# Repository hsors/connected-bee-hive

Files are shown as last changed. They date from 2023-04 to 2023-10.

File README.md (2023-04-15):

# ardbeescale-for-dummies


This repo includes the code of a a connected bee hive project together with a 65 pages document explaining the project in all details, including hardware and software 

My implementation is classical (Arduino/LoRaWan/NodeRED/InfluxDB/Grafana) but I also have included a Google Sheet integration retrieving the hive data in a google sheet, which is convenient for calibration purposes. The data being transmitted are weight, external temperature, humidity and pressure plus internal brood temperature. The data are transmitted every 15mn by default but this is configurable by sending an ad hoc downlink to the hive (a python script is provided to send downlinks to the hives). 

My code includes a weight temperature compensation algorithm using a nonlinear model which has proven to be effective and which is described precisely in the document. 

My connected bee hives include a small sirup pump allowing to feed the hives remotely. This is both convenient when the apiary is not close by and very effective to develop the hives in the spring or before winter (feeding with a small quantity of sugar very often seems to be more effective than a bigger quantity less often). The application includes a smartphone app from which the user can trigger the pumps (the app is communicating with a set of python scripts which send some uplink information to the app and get input from the app to send downlinks to the hives). From the same app, it’s possible to send a downlink which prevent the hive from sending data during a certain pre-determined time (when hives are open, we want to avoid to plot a wrong point on the hive weight curve). 

My apiary being too far away from the closest LoRaWAN gateway I had to add one (with the 4G option), which is powered from a 12V battery charged with PV panels. The gateway being quite power angry, it is switched on by an “energy saving device” only when uploads are transmitted by the scales. My code includes therefore a mechanism which synchronizes the time of each scale and the one of the energy saver device with TTN time. The  time synchronization logic is controlled by two python scripts which can be launched either manually or at regular time intervals such as once a week, to set the time of the nodes: the first script is listening to the next uplink sent by a node. The second one is triggered when this next uplink is received, at which time it sends a “set time” downlink to the node with the time of this last received uplink to which the duration between two measures is added.

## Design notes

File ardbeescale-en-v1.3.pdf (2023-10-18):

Henri SORS / h@sors.net / +33 672 99 31 36 / skype : hsors01 | ardbeescale.docx

# ArdBeeScale Project

CONTENT

1 | PROJECT PRESENTATION & TECHNOLOGICAL CHOICES | 3
1.1 | SYSTEM PRESENTATION | 3
1.2 | DEVELOPMENT ENVIRONMENT : PLATFORMIO | 4
1.3 | MICRO CONTROLLER CHOICE | 5
1.4 | DATA TRANSMISSION: LORA | 7
1.4.1 | USING AN EXISTING GATEWAY | 7
1.4.2 | USING A NEW GATEWAY | 8
1.4.3 | GATEWAY CONNECTION WITH A 4G KEY | 9
1.4.4 | SETTING UP A NODE ON TTN NETWORK. | 9
1.4.5 | PAYLOADS DECODING | 10
1.5 | ENERGY | 10
2 | SOFTWARE | 11
2.1 | MICRO CONTROLLER SOFTWARE | 11
2.1.1 | LORA LIBRARY CHOICE | 11
2.1.2 | LMIC-NODE INSTALLATION | 11
2.1.3 | HX711 LIBRARY | 13
2.1.4 | BME280 LIBRARY | 14
2.1.5 | LIBRARIES FOR THE DS18B20 TEMPERATURE SENSOR | 15
2.1.6 | PAYLOADS FORMATS | 16
2.1.7 | MAIN SKETCH –UPLINKS AND DOWNLINKS PROCESSING | 18
2.1.8 | MAIN SKETCH – POWER MANAGEMENT | 18
2.1.9 | MAIN SKETCH; TIME MANAGEMENT | 19
2.1.10 | DEALING WITH UNEXPECTED HANGS THANKS TO THE INTEGRATED WATCH DOG | 20
2.2 | JS CODE FOR PAYLOAD DECODING (TO BE LOADED ON TTN CONSOLE) | 20
3 | INTEGRATION WITH GOOGLE SHEET | 21
3.1 | MQTT | 21
3.1.1 | PROTOCOL | 21
3.1.2 | MOSQUITTO | 21
3.1.3 | MQTT & PYTHON | 23
3.2 | PYTHON CODE RUNNING ON RASPI SERVEUR | 24
3.2.1 | PROGRAMS & DATA ORGANIZATION | 24
3.2.2 | PYTHON CONFIGURATION FILE | 25
3.2.3 | RETRIEVING DATA FROM MQTT AND TEMPORARY STORAGE | 25
3.2.4 | DATA STORAGE IN A GOOGLE SHEET FILE | 26
3.2.5 | INSTALLATION | 28
4 | BLYNK | 29
4.1 | GENERAL PRINCIPLE | 29

Ardbeescale | Page 2 | Novembre 2021
4.2 | BLYNK SET-UP | 29
4.3 | PROGRAMMING | 30
4.4 | BLYNK INSTALL ON RASPBERRY | 32
4.5 | CONFIGURATION OF BLYNK APP | 32
4.6 | UPDATE AS OF FEBRUARY 2023 | 33
5 | NODE-RED – INFLUXDB – GRAFANA INTEGRATION | 33
5.1 | PRINCIPLE | 33
5.2 | NODE-RED | 35
5.2.1 | FETCHING UPLINKS IN NODE-RED | 36
5.2.2 | DATA STORAGE IN INFLUXDB | 37
5.2.3 | SENDING DOWNLINKS | 38
5.2.4 | NODE-RED DASHBOARD ON A SMARTPHONE | 39
5.3 | VISUALIZATION WITH GRAFANA | 39
6 | HARDWARE & WIRING | 40
6.1 | LOAD CELL & SUPPORT FRAME | 40
6.2 | WIRING OF THE MICRO CONTROLLERS AND ASSOCIATED CONNECTORS | 41
6.2.1 | WIRING OF BME280 SENSOR | 41
6.2.2 | WIRING OF THE HX711 BOARD | 42
6.2.3 | WIRING OF THE RELAY BOARD | 42
6.2.4 | MICROCONTROLLER WIRING | 42
6.2.5 | MODIFICATION OF THE BATTERIE ENCLOSURE | 48
6.2.6 | CHARGING THE BATTERY | 48
6.2.7 | CONTENT AND CHOICE OF THE ENCLOSURE | 48
6.2.8 | MOUNTING THE ENCLOSURE ON THE SCALE | 50
7 | WEIGHT MEASURE ACCURACY | 50
8 | HOW TO ACCESS A GOOGLE SHEET FILE FROM PYTHON SCRIPT | 51
9 | WEIGHT TEMPERATURE COMPENSATION | 51
9.1 | PROBLEM STATEMENT | 51
9.2 | PROPOSED NONLINEAR MODEL | 53
9.3 | IMPLEMENTATION | 57
10 | POWER SAVING UNIT | 58
10.1 | INTRODUCTION | 58
10.2 | ABOUT THE HARDWARE | 59
10.3 | SOFTWARE | 60
10.4 | UPLINKS SENT BY THIS ENERGY SAVING DEVICE: | 62
10.5 | SETTING UP THE TIME OF THE ENERGY SAVER UNIT. | 62
10.6 | MAKING SURE EVERYTHING IS IN SYNCH… | 63
11 | - LIST OF FILES | 64
12 | - SETTING-UP THE SYSTEM… | 65

Ardbeescale | Page 3 | Novembre 2021

### 1 PROJECT PRESENTATION & TECHNOLOGICAL CHOICES

### 1.1 System presentation

Main features of « ardbeescale » :

- Hive weight measurement with a Bosche H40 load cell
- Temperature, pressure and humidity measurement with a BME280 sensor
- Internal hive temperature measurement with a DS18B20 one wire sensor
- Data transmission on the LoRaWAN TTN network at a configurable frequency from once per minute to once per 24H
- Use of an Arduino low consumption microcontroller (Adafruit LoRa Feather M0, based on SAMD21 processor), powered by two 18650 batteries (3.7V) rechargeable on an external USB plug.
- The device includes a relay and the ad hoc hardware & software needed to remotely trigger a syrup pump from a smartphone

TTN's LoRaWAN network is widely present in my region (Grenoble/France, the home of Cycleo, the company that invented LoRa technology, which Semtech, a US company bought in 2012) and therefore in many places in this region it is possible to install a LoRa based hives using existing gateways. However my apiary happens to be a bit too far away from the closest gateway and I have therefore chosen to add one, which is connected to the Internet through a 4G key and powered by a 12V battery connected to two PV panels.

To retrieve the data emitted with LoRa protocol by the hives, I use a raspberry pi that communicates via the internet with the TTN network. Two types of integration have been developed:

- Through two python programs that run on the raspberry pi
- getdataFromUplink.py which retrieves (thanks to the MQTT protocol) the data sent by the hives to the TTN server and places them in a directory of the raspberry server
- storedata.py which permanently checks this directory and stores the data that have been placed in it (by getdataFromUplink.py) in a google sheet file in which they are visualized on charts. These programs are designed to manage a maximum of 6 connected hives per apiary on a Google sheet file.

This integration had some reliability problems that seem to be related to the availability of the google sheets files (I didn't manage to implement the error checks that could allow to totally get rid of these problems and it turns out that the storedata.py program crashes from time to time, about once a month for a reason that I failed to identify)

- Based on the limitation of the google sheet integration, another one has been developed using a standard IOT stack: the data are retrieved using the MQTT protocol, using an MQTT node on nodeRed that listens to the TTN brocker. Another node of nodeRed stores the data in an influxDB "time series" database and the data are visualized using Grafana.

The data transmitted from the hive to the server (uplinks) are weight, external temperature, internal temperature, humidity, pressure and battery voltage, all on 8 bytes. A last byte is added to secure the transmission of downlinks: it contains the value of the last downlink received allowing to check that this downlink has been received and processed.

The data transmitted by the server to the hive as downlinks allows :

- To change the frequency of measurements
- To trigger the pump feeding the hive with sirup
- To hold measurements for a certain time in order to avoid false measurements during hive manipulation which otherwise would pollute the weight curve of the corresponding hive.
- To reset the value of the last downlink received by the server
- To set the time of the micro controller in order to be able to take measurement at precise moments. This is needed because in winter there is not enough energy to power the gateway permanently; a special device (hso-energysaver) has been developed to switch it ON at

Ardbeescale | Page 4 | Novembre 2021

precise moments and the hives should transmit data at the same time; hence the need to set the same time on all devices). Details in 2.1.9

The enclosure includes following inputs / outputs:

- Three female Jack connectors :
- Two that are very close to each other (mounted in parallel) allow to bring in and out (to the next hive) the 12V necessary for powering the pump
- One is apart and brings 12V to the pump
- A micro USB connector (connected to the one of the Adafruit board itself) is available on the enclosure. It allows to recharge the batteries (because the board includes a charger) and to reprogram the processor without having to open the case.
- A push button triggering the pump in order to easily calibrate it.
- There is no connector for either the BME280 sensor or for the load cell: corresponding cables pass through the housing.

The enclosure also includes an on/off button which is needed to easily reprogram the device without opening it (reprogramming the device is possible only during program start-up; later on the device is almost all the time in sleep mode and would not respond to the serial port)

The firmware also includes a temperature compensation model that reduces fluctuations in weight measurements when temperature changes. See chapter Error! Reference source not found.

### 1.2 Development environment : platformIO

platformIO seems to be a quite powerful and widely used development tool, the most common alternative being Arduino IDE which is deemed to be less feature full and does not have a debugger. The installation procedure of platformIO can be found here. (https://circuitdigest.com/microcontroller-projects/programming-arduino-using-platform-io-to-blink-an-led) There is also a good and clear explanation video here (https://dronebotworkshop.com/platformio/) including explanations in text form.

When programs developed with Arduino IDE are used (.ino extension), it’s needed to convert them into platformIO file (.cpp extension). See explanations in the platformIO doc here. (https://docs.platformio.org/en/latest/faq.html#convert-arduino-file-to-c-manually) It is the same code, the main difference being the order in which functions are declared.

It seems to be possible to use Python on platformIO with Arduino (by charging the ad hoc extension) but I haven’t tried. Documentation is here. (https://code.visualstudio.com/docs/python/python-tutorial)

To use platformIO, Visual Studio Code has to be loaded first and then the PlatformIO plug-in (by clicking on the "extension" icon, type platformIO and it will load automatically).

A good video tutorial from a Canadian guy is available here. (https://www.youtube.com/watch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)

In platformIO, different projects are stored in different sub directories of /platformIO/Projects on the Mac. You can open several projects at the same time in the same workspace. To add a project in a workspace select " add folder to workspace " (if you just do " open folder " it opens the project but it closes everything else, including the current workspace). To remove a project from the open workspace select "remove folder from workspace".

You can save a workspace containing several projects. Re opening it opens all the projects.

Sometimes and for some reasons, I met difficulties in loading my projects in PlatformIO (impossible a add a folder). I resolved this by clicking on the small “home” icon and then could choose the project to be loaded… I need to dig more in PlatformIO to fully understand how it works…

Libraries installation :
Click on the home icon, then choose "library". The library is installed only for the project that needs it. The library is added in the .pio directory (therefore not visible in the finder).

Ardbeescale | Page 5 | Novembre 2021

Alternatively, it’s possible to add a library by adding the name of its libdeps (library dependency) in platform.ini which is project specific:

lib_deps =
fabyte/Tiny BME280 @ ^1.0.2
In fact it seems that adding some libraries will automatically add this line to platformio.ini but is other instances, one need to load the library as described above and also add the reference to it in the file platformio.ini (as explained in the “installation” tab available once you have added the library using the “home” icon of PlatformIO. Need to double check as I am not fully sure…

At compilation time, the library will be loaded and it will show up in folder .pio/libdeps. In order to remove it, simply remove its reference in the libdeps and remove the directory of this library which resides in .pio/libdeps
Official documentation of platformio.org is here. (https://docs.platformio.org/en/latest/librarymanager/quickstart.html)

For information I have met an issue with PlatformIO which I was unable to resolve by myself. For some reasons, all of a sudden it became impossible to list the installed libraries. Clicking on the home icon and then on Libraries et selecting “installed libraries” triggered a pop up error message saying:

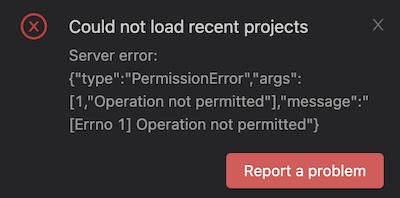
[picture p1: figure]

I posted a question about this issue on PlatformIO community forum and a PlatformIO support guy instructed me to type the following command in the system terminal:
rm ~/.platformio/homestate.json
It resolved the problem but I completely fail to understand why and what happened.

### 1.3 Micro controller choice

Initially I started with a Moteino (https://lowpowerlab.com/shop/product/99) which is a very small size Arduino compatible board (ATmega328p processor), proposed par lowpowerlab. (http://www.lowpowerlab.com/) This Moteino board has a piggy back LoRa option, connected to the SPI bus. The supplier is in the US (knowing the radio module comes from China) but there is now a distributor in Germany (Welectron) which is selling Moteino in Europe with the a European frequency option (RF95).

But in the end, because Moteino turns out to be a 8bits processor with not enough memory for the "standard" LoRaWan library (only the old version of the library which is not supported anymore would work) I had to drop this board and I finally selected Adafruit Feather M0 with RFM95 Lora Radio -900MHz (https://www.adafruit.com/product/3178) (which can work at 868MHz, the authorized frequency in Europe). I paid 51€ttc on Amazon. Documentation is here. (https://cdn-learn.adafruit.com/downloads/pdf/adafruit-feather-m0-radio-with-lora-radio-module.pdf) This board, which is Arduino zero compatible, is powered with 3.3V and is based on an Atmel 32 bits ARM ATSAMD21G1processor. It carries much more memory than Moteino and includes a micro USB interface with the ad hoc charger circuitry allowing to recharge the battery by plugging a micro USB cable connected to a power source. It also includes a battery connector.

Ardbeescale | Page 6 | Novembre 2021

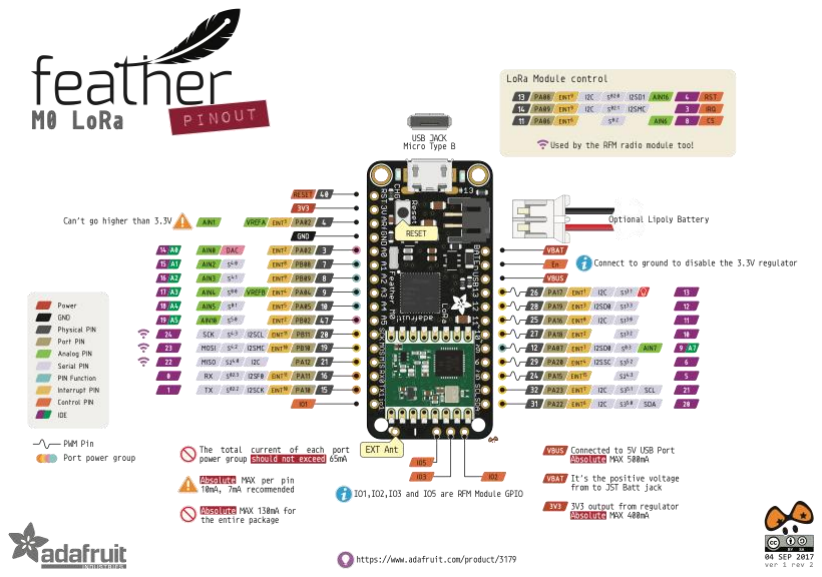
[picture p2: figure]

This board can be powered with a 5V power supply connected to micro USB plug; the internal circuitry will convert the voltage to 3.3V.

There | is | an | HX711 | (A/D | converter | for | the load | cell) driver | available | for | this | board
(https://github.com/bogde/HX711) which is the one used by hiveeyes.

Adafruit busIO driver must also be loaded in order to be able to use the I2C bus, which needed for the BME280 device (temperature, humidity and pressure sensor).

For the antenna, I initially bought one on Amazon for 11€ but when testing this antenna I found that I lost 10 to 20db on the RSSI of the received signal compared to an antenna made of a simple wire of ¼ of the wavelength. So I abandoned the idea of an SMA antenna and just used a simple wire that I tilted a bit to fit into the box. To make something more sophisticated, the best thing to do is to refer to this forum (https://lowpowerlab.com/forum/rf-range-antennas-rfm69-library/alternative-pcb-dipole-designs-(433-868-and-915mhz)/) which explains how to make a half wavelength dipole antenna using the right (https://www.amazon.com/RP-SMA-Female-Pigtail-Antenna-Coaxial/dp/B072VWKXCR/?th=1) cable of the right length to connect it to the board.

Ardbeescale | Page 7 | Novembre 2021

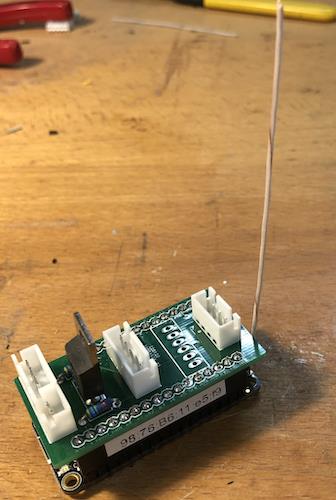
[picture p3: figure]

This is a picture of the module (with add-on board plugged in, as explained later in this document) equipped with a ¼ wavelength antenna (8.62cm):

### 1.4 Data transmission: LoRa

It was a Grenoble-based company that developed LoRa (Cycleo, created in 2010), bought by Semtech two years later for $5M... The LoRa alliance was created in 2012.

One way to become familiar with the technology is to read the this page (https://www.thethingsnetwork.org/docs/devices/node/) presenting what they call "the things node" which is a simple device allowing to make tests. This same page has a menu that presents other devices.

LoRa protocol is close to the hardware but there is an associated network protocol, called LoRaWan.

The web site www.thethingsnetwork.org manages a free LoRaWan network. There is a « quick start (https://www.thethingsnetwork.org/docs/quick-start/) » page containing multiple explanation videos and listing several popular development boards. In particular, there is a link on some videos from TTN explaining how to do the set-up of a LoRa device or a LoRa gateway and which speaks about payload formaters (for getting the data correctly formatted).

The TTN community offers a tool called "the things stack" which allows to connect to a LoRaWan network and to manage all LoRa devices, including end nodes and gateways. The same tool allows to format the received data so that it is readable (payload formater). On TTN's LoRaWAN network, you can connect to the network even if you don't have a gateway, any gateway on the network being usable, as long as it is accessible (=near enough).

There is very wide variety of LoRa compatible sensors of all kinds: see a list on the TTN site here. (https://www.thethingsnetwork.org/device-repository/)

With TTN, there are limitations in the number of messages transmitted and their length (max: 30s air time/day. See TTN « fair policy (https://www.thethingsnetwork.org/forum/t/fair-use-policy-explained/1300) ».

TTN web site has a documentation page (https://www.thethingsnetwork.org/docs/lorawan/) on LoRa and LoRaWAN.

### 1.4.1 Using an existing gateway

TTN publishes a web page with the latest network coverage indications: https://ttnmapper.org

Ardbeescale | Page 8 | Novembre 2021

This mapping can be updated by users using a TTN tool. There is a page on the TTN site that gives all the explanations

Most cities and their suburbs are covered by the TTN network.

### 1.4.2 Using a new gateway

To use the hives in a somewhat deserted place (= not covered by a LoRa gateway of the TTN network), it is necessary to set up a new LoRaWan gateway and hook it up to the TTN network. See possible solutions on this page. (https://www.thethingsnetwork.org/docs/gateways/) The best is probably to buy the gateway offered by thethingsindustries here. (https://fr.rs-online.com/web/p/modules-de-developpement-de-communication-et-sans-fil/2018876) There is a (https://www.thethingsnetwork.org/forum/t/ttig-outdoor-housing-with-omni-antenna-in-1-hour/29523) thread on the forum that explains how to transform the indoor gateway into an outdoor gateway. I also asked the question of choice of gateway on the TTN forum and I received an (https://www.thethingsnetwork.org/forum/t/choosing-a-gateway/53040/18) answer that seems interesting if you want an outdoor gateway.

There is also a Raspi HAT which looks interesting and is unexpensive here (https://www.robotshop.com/eu/fr/hat-raspberry-pi-lora-gps.html) but I was told on the forum that it doesn’t do the job correctly.

There is a page (https://www.thethingsnetwork.org/docs/gateways/start/build/) on TTN explaining how to make its own gateway and which lists all existing LoRaWan gateways.

### 1.4.2.1 Installing the TTIG gateway

I started by using an indoor gateway (the things indoor gateway also called TTIG). For memory, on this gateway, EUI is 58A0CBFFFE802B8B, WIFI code is wJdMxcHv and in the console I have chosen the id ttig-hso1. Installation instructions are here. (https://www.thethingsindustries.com/docs/gateways/thethingsindoorgateway/)

Note: once the gateway has been connected to the TTN network, it is easy to change the WIFI network to which it is connected: press the set-up button for 10s (until the LED flashes orange), this will turn the gateway into a WIFI access point which SSID is MINIHUB-XXXXXX. We then need to connect to this
access point (WIFI password is wJdMxcHv in my case), and go to the page | 192.168.4.1 | and click
"save & reboot" after selecting the network on which we want the gateway to connect.

Attention : there is a known bug in the TTIG indoor gateway: if the gateway is requested less than 1 time every X minutes (I think X is around 15), the gateway disconnects the LoRa nodes and then refuses all the downlinks coming from them.

### 1.4.2.2 Installation of the Dragino gateway DLOS8 Outdoor

I also installed a Dragino outdoor gateway.

When powered on, it exposes a WIFI network called dragino-xxxxxx which password is dragino+dragino. Once connected, the gateway can be accessed at address 10.130.1.1

## User Name: root Password: dragino

We can then configure the WIFI access (need to check the box "Enable WIFI WAN client" which by default is not)

Ardbeescale | Page 9 | Novembre 2021

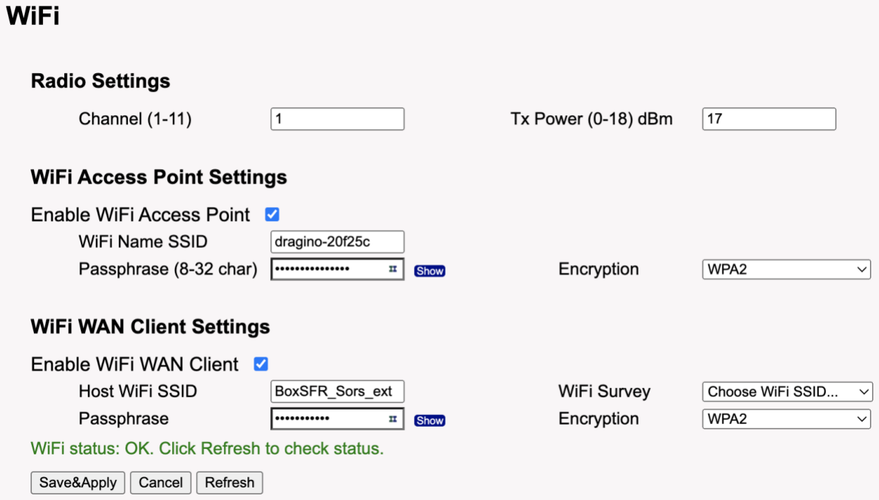
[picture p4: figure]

Meaning of the gateway LEDs :

✓ SOLID GREEN: DLOS8 is alive with LoRaWAN server connection.

## ✓ BLINKING GREEN:

a) Device has internet connection but no LoRaWAN Connection.
or
b) Device is in booting stage, in this stage, it will stay BLINKING GREEN for several seconds and then RED and YELLOW will blink together.

✓ SOLID RED: Device doesn’t have Internet connection.

Then we need to create the gateway on TTN network, using the following link : https://eu1.cloud.thethings.network/console/gateways

The "gateway Id" can be found in the LoRaWAN menu of the Dragino gateway configuration page. This is also where you choose the "server address" (eu.cloud.thethings.network) and the service provider (The Things Network v3).

### 1.4.3 Gateway connection with a 4G key

Initially I tried to use a 4G key as a WIFI "access point", the dragino being supposed to connect to Internet through this access point. For some reason (which I fail to understand), the dragino refuses to connect to this access point even though it connects without any problem my home WIFI access point.

Even if I bought the Dragino DLOS8 gateway without the 4G option (the “WIFI only” version was less expensive), I realized that the product was actually including a slot for a SIM card and when I tried to plug a SIM card in it, the device quickly connected to the Internet after I correctly configured it. What a piece of luck !

1.4.4 Setting up a node on TTN network.

There are two ways to activate a node on TTN: OTAA (Over the Air Activation) and ABP (Activation By Personalization). I understand that OTAA is preferable because the corresponding protocol

Ardbeescale | Page 10 | Novembre 2021

includes a handshake that seems to guarantee better security. Each type of activation involves a different code on the micro controller; I have used the OTAA code.

Procedure :

1. Go to the TTN console in the "Applications" section
2. Create a new application and give it a "unique application ID".
3. Then create the new device (node). There are two options to create a new device; choose "Manually" and "Node".
4. Specify which version of TTN is supported by the library. You have to search in the library files to find this information which is in the library.properties file (1.0.3 in my case)
5. Fill frequency plan (Europe)
6. Click on "generate"; the system creates a unique deviceEUI. (EUI means "Extended Unique Identifier").
7. The appEUI (or joinEUI) is to be filled with 0's if the device you want to register does not have a specified devEUI (which is the case for DIY devices).
8. The appkey is generated by the system when you press the "generate" logo.)
9. The "end Device Id" has to be filled in with a string of your choice. Be careful when you create a device Id, deleting it does not really remove it from the TTN database and it is impossible to create a new device Id that is the same as the one you have deleted.
10. Click on « generate » so that the system creates the device on TTN

See section 2.1.2 LMIC-node (text in blue) for explanation on how to update the library parameters for the newly created node.

### 1.4.5 Payloads decoding

The TTN console allows you to load a small javascript program that will retrieve the data received by the node and decode them by loading them into different variables that can be transmitted and retrieved by a python program running the paho library. See details in section 2.2

### 1.5 Energy

The power of LoRa emission is apparently adjustable by software (I do not know how...)

It is indicated in the manual of the Feather M0 LoRa board that with a transmission power of 20dBm, a current of 130mA is needed during 70ms in order to transmit a payload of 20 bytes. Therefore sending such a payload requires an energy amount equal to :

### E = 0.13 × 7 × 10⁻²A. s = 0.13 × 7 ×

10⁻²

### 3600 = 2.5μA. ℎ

It is therefore not the sending of payloads that consumes a lot of energy even if we send them regularly. If we send 6 payloads per hour, each with 20 bytes, the energy consumed each day is 360 μA.h, meaning that a single battery could last several years.

However, the quiescent current of the micro-controller together with its radio is much higher: 13mA total, including ~2mA is for the radio itself. This is about 300mAh, meaning that a 3000mAh battery would last 10 days... It is therefore essential to put the controller in standby mode between measurements if we want to achieve a reasonable battery lifetime.

It seems that the power consumption is very variable depending on the software options chosen. See this blog (https://tinkerman.cat/post/low-power-weather-station-bme280-moteino/) which gives examples (weather station using a moteino). The main idea is to put the processor in sleep mode and to wake it up at regular interval using timer interruptions

Information on power consumption here. (https://www.arduino.cc/en/Tutorial/ArduinoZeroPowerConsumption)
See also a good explanatory video here (https://www.youtube.com/watch?v=wmWqkJ97Zsc) with the associated blog (with the code) here. (https://forcetronic.blogspot.com/search?q=SAMD21+sleep) The principle consists in using the library RTCzero.h which uses the real time clock in order to wake-up the chip after a predefined period of sleep.

The author explains that it’s possible to change the source of the RTC clock, which by default is the external clock (you can choose an internal clock) and that this saves 10µA at the cost of a certain

Ardbeescale | Page 11 | Novembre 2021

loss of precision (10µA is 24mA.h in 100 days, so it is not worth optimizing by losing precision). You can find the documentation of RTCZero on arduino.cc (https://www.arduino.cc/reference/en/libraries/rtczero/) web site.

The problem in our case is that we can't stop the processor anywhere without disturbing the timing of LMIC.

The only way I found to interrupt the processor without messing up the LMIC timing is to introduce the sleep at the end of the routine that handles the event « EV_TXCOMPLETE ». It’s also necessary to delete the last line of the « doWorkCallback » callback function which reschedules the callback function [os_setTimedCallback(…)] and replace it, at the end of the code treating the event EV_TXCOMPLETE with a line launching immediately the callback function [os_setCallback()] as soon as the processor wakes-up. The sleep time of the processor is equal to the interval between two consecutive measurements as specified in the constant DO_WORK_INTERVAL_SECONDS in platformIO.ini file (in reality it will be a little bit longer because you have to add to this time the execution time of the callback function and the processing of the following events (about ten seconds in total) plus the time needed to process the downlinks if there are any (this can be quite long in the case of a downlink triggering the pump because the routine processDownlink() waits until the pump turns off before returning).

Power consumption calculations: the board consumes about 13mA when it is awaken and it stays awaken for about 8 seconds to send its uplinks each time it is woken up. If we send 4 uplinks per hour, the daily consumption will be :

E =

13×10⁻³×8

3600

× 4 × 24 = 2.77mA. ℎ, which is about 1A.h per annum. In reality this is higher, which

means that the whole process can be improved.

### 2 SOFTWARE

### 2.1 Micro Controller Software

### 2.1.1 LoRa library choice

This page on TTN, (https://www.thethingsnetwork.org/forum/t/overview-of-lorawan-libraries-howto/24692/) explains that the original library from IBM has been ported and has forked. Now the last version to be used preferably is the MCCI LMIC (https://github.com/mcci-catena/arduino-lmic) version, the original version Classic LMIC (https://github.com/matthijskooijman/arduino-lmic) being a possible solution when RAM space is limited (which was the case with Moteino that I initially tested, before dropping it because the corresponding library is not supported anymore; hence the move to Adafruit board)

This library, which is to be loaded on PlatformIO or on the Arduino IDE, gives some examples of applications but it specifies that these examples are limited and suggests to use rather the work of Lopes Parente : LMIC-Node (https://github.com/lnlp/LMIC-node) available on github. This is a complete application example, sending uplinks et receiving downlinks, using PlatformIO development environment and preconfigured for a variety of different LoRa board, including the Adafruit board that I chose. It’s also a good idea to have a look at the Adafruit site which includes a section showing how to set-up their board for TTN. It’s here (https://learn.adafruit.com/the-things-network-for-feather/overview) and it includes explanation on the code and how to decode the « payloads »

Here are other possibly useful references :

1) I have found a Dutch person which has used the LMIC library with the same HF module with an Arduino. See here. (https://www.mobilefish.com/developer/lorawan/lorawan_quickguide_build_lora_node_rfm95_arduino_uno.html) But the proposed activation method is ABP and not OTAA.
2) There is also a videao from Andreas (https://www.youtube.com/watch?v=duwUwXt-hs8) Spiess which seems to use the same library with an Arduino shield.

### 2.1.2 LMIC-node installation

Extract from LMIC-node (https://github.com/lnlp/LMIC-node) on github :

- Basic steps to get a node up and running with LMIC-node:
- Select a supported board in platformio.ini.

Ardbeescale | Page 12 | Novembre 2021
- Select your LoRaWAN region in platformio.ini.
- Provide the LoRaWAN keys for your node (end device) in lorawan-keys.h.
- Compile and upload the firmware and you're ready to go!

LMIC-node includes all the mechanics needed to send uplinks and receive downlinks so that the only code to add is the one necessary to read the sensors and create the payloads (which will be sent by the main LMIC-node sketch) and to decode the received downlinks in order to take the appropriate actions according to their contents. LMIC-node package doesn’t include sleep mode so it had to be added.

LMIC-node installation is quite simple. The procedure and the attention points are the followings :
(the lines shown in blue are the ones that need to be modified when making a copy/paste of the PlatformIO workspace of an existing connected scale to create a new workspace for a new scale)
- A wire connection need to be added on the Adafruit board (it’s explained both in Adafruit (https://learn.adafruit.com/the-things-network-for-feather/arduino-wiring) doc and in the platformio.ini file of LMIC-node). The connection is between DIO1 pin of the radio module and pin GPIO6 of Adafruit board.
- A project (“ardbeescale”) must be created in platformIO, specifying “Adafruit Feather m0” as the board
- The file platformio.ini must be replaced by the one of LMIC-node
- The content of the file LMIC-node.cpp must be copied into main.cpp, replacing the existing content in this file
- The file LMIC-node.h must be copied in the directory include
- The controller board (adafruit_feather_m0_lora in my case) is chosen by removing the comment of the corresponding line in file platformIO.ini (and by commenting the line above « <platformio.ini board selector guard> »
- The « board support file » corresponding to the controller board that I use must be copied in platformio (file bsf_adafruit_feather_m0_lora.h). Need to create a directory in src (src/boards) and put this file here.
- The region setting is done in file platformIO.ini, line 159. Default is Europe.
- In the file platformio.ini, the right library must be selected (mcci-catena/MCCI LoRaWAN LMIC library, the last version). All the lib_deps (libraries dependencies) that are useless in our case (olikraus/U8g2 for example, which is a driver for OLED) and it’s of course needed to add all those libraries that the system will use (HX711 for example)
- The LoRa « keys » must be specified in the file lorawan-keys.h (see lorawan-keys-example.h
on | gitHub). The content of this file must be copied/pasted in a different file name
(lib/keyfiles). The keys include AppEUI (sometimes called | joinEUI), deviceEUI and
appKey ; they are provided by TTN on the TTN console when the node is created. Warning, the keys are provided on TTN console under the wrong format. In order to get the right format :
- For AppEIU & devEUI :
- click the <> button (1st left) to toggle between hex and C-style
- click the second button from the left to toggle to lsb format
- click the copy button on the far right
- For AppKey : same but msb first format must be kept (do not click on the button changing msb to lsb)
- DO_WORK_INTERVAL_SECONDS value in file platformIO.ini must be set in order to determine the frequency at which processwork loop is called.

Ardbeescale | Page 13 | Novembre 2021
- To send uplinks, LMIC-node (https://github.com/lnlp/LMIC-node) uses port 10, which is not the default one. For downlinks, this is port 100.
- LMIC-node (https://github.com/lnlp/LMIC-node) code includes a portion where the node sends an uplink containing the value of a counter, the counter being incremented at each loop. The counter can be reset by sending 0xC0 to the node with a downlink. Obviously this part of the code must be removed but it’s useful to play with this example code in order to check that everything works fine.
- LMIC-node (https://github.com/lnlp/LMIC-node) includes a constant called « DEVICEID » used to identify a node (especially in the status information sent on the serial port or on the display when there is one). By default this DEVICEID is the devideId of the board as defined in the BSF (Board Support File), which is in directory /src/board of platformIO. In my case, the default deviceId was feather-m0. This default value can be overridden by defining the constant DEVICEID in file lorawan-keys.h
- LMIC-node package on github includes a javascript file lmic-node-uplink-formatters.js (https://github.com/lnlp/LMIC-node/tree/main/payload-formatters) to be loaded on TTN in order to decode the data emitted by the node (the uplinks). This is done from the TTN console after selecting the application corresponding to this node, by clicking on the left « payload formaters » / uplinks and then on the right the option “java script” must be selected and then the code that was in the file lmic-node-uplink-formatters.js has to be copy/pasted with the ad hoc changes.

Warning : LMIC-node example transmits only integer data (the counter value).

Warning : LMIC-node example only transmits integer data (the counter value). Therefore the coding of these data to transmit them in the payload is very simple and on the other hand the javascript code to load on the TTN console is also very basic. If the data are of “real” type, you have to use the library's "built-in" functions that convert the real into two integers and the javascript code (on the ttn console) does the opposite. You can find examples of coding in the Adafruit example (https://learn.adafruit.com/the-things-network-for-feather/overview) which transmits the temperature and the humidity and the javacript code decoding the payload data in the readme of the library. See the explanation in red here below

I have also tried to use the instructions from Adafruit (https://learn.adafruit.com/the-things-network-for-feather/overview) in a different implementation (just to try):

- Need first to install the library MCCI LoRaWAN LMIC library
- Need to modify file lmic_project_config.h (in the directory containing the library) in order to select the region
- The compilation of the code ttn-otaa-feather-us915-dht22.ino, copied in main.cpp generated an error "do_send was not declared in this scope". I have added a « forward declaration » of this function on top of the code line 33 : void do_send(osjob_t* j);
- In the setup()routine, there is a line selected the « subBand ». This notion doesn’t exist in Europe and therefore the line LMIC_selectSubBand(1)must be commented

To be noted : in the Adafruit example (explanation here), (https://learn.adafruit.com/the-things-network-for-feather/arduino-code) the readout of the DHT22 temperature is converted in two bytes (of type uint16_t, meaning unsigned integer 16 bits) with a function of the library called LMIC_f2sflt16(x)for « float to signed float 16 bits », x being comprised between -1 and +1 (in order to respect this, temperature is divided by 100). In summary,
LMIC_f2sflt16(x)function | takes | a real number x greater than -1 and lower than 1 and
transforms it into an integer of two bytes. To get the payload, it’s therefore necessary to convert back those two bytes into the original real number. The javascript code supplied by Adafruit (https://github.com/adafruit/Adafruit_Learning_System_Guides/blob/main/TheThingsNetwork_Feather/ttn_lmic_dht22_decoder.js) does the job (it uses the code supplied here (https://github.com/mcci-catena/arduino-lmic#javascript-decoder) in the readme LMIC (https://github.com/mcci-catena/arduino-lmic) library).

### 2.1.3 HX711 Library

Just for information, I have learnt on hiveeyes forum (https://community.hiveeyes.org/t/8266-homie-battery-powered-or-bienenwaage-2-0-nodemcu/4231/5) the existence of a different ADC chip which supposedly works better that the HX711: the chip NAU7802. I had already bought all my HX711and I have therefore not used this new one.

Ardbeescale | Page 14 | Novembre 2021

Need to read https://hiveeyes.org/docs/arduino/firmware/scale-adjust/README.html There are sketches used to adjust the scale parameters and some interesting links useful to better understand load cells.

Searching « arduino hx711 library » on Google brings up this page (https://www.arduino.cc/reference/en/libraries/hx711-arduino-library/) of arduino.cc site and it seems this is the library that is used by the Hiveeyes team. The examples are self-explanatory.

Clicking « read the documentation » on the same page brings up a github page which readme points on the hiveeyes forum. There is in particular an interesting article (https://community.hiveeyes.org/t/analog-vs-digital-signal-gain-amplifiers/380/6) on the measure theory.
Summary : Oddly enough, the sensitivity of a load cell is measured in mV/V (typically 2mV/V). This is the measurement of the voltage across the Wheatstone bridge per volt of excitation voltage of this bridge, when the full load of the load cell is applied. 2mV/V means that if we apply 5V as excitation voltage, we will measure 10mV on the Wheatstone bridge when the full load is applied. To measure this voltage, the ADC will first apply a gain (PGA for Programmable Gain Amplifier). If the ADC can measure between 0 and 5V and the gain is 128, this means that the range applicable to the input of the ADC is about 40mV (5/128). However, we are only going to apply 10mV, so we will only use 22 of the 24 available bits. In addition the ADC is associated with a noise which is specified at 17nV. But one bit of the ADC corresponds to 2.384nV (10mV/22bit). So we lose about 3 bits. And he continues to state all the reasons why we lose precision...

There are many HX711 libraries available in platformIO. To find the one used by Hiveeyes, you have to type "Bogde" in the search field. But I saw on a post (https://community.hiveeyes.org/t/esp8266-deep-sleep-with-hx711/4218/3) on the Hiveeyes forum that Clemens Gruber (one of the Hiveeyes gurus) mentioned another library.

It seems that the two libraries are the same but I noted that in the original one (https://github.com/bogde/HX711) the updates are more recent so it is the one I choose.

### 2.1.3.1 Usage of HX711 library

The library is not very well documented. It provides the tare() function which allows to tare the scale before the measurement but it does not work for a scale on which the weight is permanently applied. For that you have to use the function set_offset(xx) where xx is the value read on the ADC when no weight is put on the scale.

Other useful functions are :

- read(n) direct reading of the ADC output (average over n measurements)
- get_value(n) reading of the ADC output minus the tare value
- set_scale(ratio) to indicate to the scale the number of ADC units per gram
- get_unit(n) direct reading of the applied weight (= get_value(n)/ratio)
- power_up() and power_down() wake-up and standby of the ADC

### 2.1.4 BME280 library

Warning: the microcontroller documentation indicates that there is no pull-up on the SDA and SCL I/O and that it is "possible" that it is necessary to add a pull-up resistor from 2.2K to 10K. In fact, after a few hours of normal operation, the BME280 reading stopped working correctly and I added two pull-up resistors. To limit the consumption I used 50K resistors and it worked without problem. Nevertheless the corresponding power consumption is not negligible. If the bus is LOW all the time, the resistor will generate a consumption of 70 µA, which corresponds to 0.6Ah in one year. It could therefore be useful to connect the pull-up resistors not to the 3.3V but to the output of a GPIO and to put the 5V only when it is needed.

In order to use the I2C bus, the driver has to be loaded: #include <Wire.h>
To verify that the microcontroller detects the sensor on the I2C bus, I used an I2C scanner found here. (https://wiki.seeedstudio.com/Arduino_Software_I2C_user_guide/) It detects the BME280 at address 0x76. Problem : the Adafruit library waits for the sensor at the I2C address 0x77. We can either change the address of the sensor (complicated, need to tinker on the sensor) or, much simpler, change the line that initializes the code by adding the address :

Ardbeescale | Page 15 | Novembre 2021

Line status = bme.begin(); must be replaced by status = bme.begin(0x76);

I use the Adafruit BME280 library which allows to communicate either in SPI or in I2C (simpler). You have to load this library and the one called "Adafruit Unified Sensor" (I think it loads automatically when you load the other one).

The library is written for the Arduino IDE which accepts that functions are defined after the code that uses them, which is not true with PlatformIO; it is therefore necessary to move the code of these functions to the beginning of the program.

To load the library, following lines has to be added in the file platformIO.ini after « lib_deps = » :

adafruit/Adafruit Unified Sensor@^1.1.4
adafruit/Adafruit BME280 Library @ ^2.2.2

For the program to compile it is also necessary to add in the file main.cpp the I2C driver (#include <Wire.h>)as well as the Adafruit libraries:

#include <Adafruit_Sensor.h>

#include <Adafruit_BME280.h>

Then the BME280 object is created :
Adafruit_BME280 bme;
(to be added in the first portion of the code marked « user code begins here » in main.cpp)
Then the sensor has to be initialized in the last section of the user portion of the code, at the end of the same file, by adding the line : status = bme.begin(0x76);
Along with the code taking the measure.

The power consumption of this sensor is <1mA in read mode and <5uA in idle mode.

Update April 2023: when the BME280 breaks down for some reason, the Adafruit library code gets stuck waiting for it indefinitely. This not only prevents any further weight measurement to be taken and transmitted but also prevents the software to put the processor in sleep mode, which of course sink to much current and empties the battery very quickly. I have therefore changed the library and am now using the Sparkfun one.

### 2.1.5 Libraries for the DS18B20 temperature sensor

As explained in chapter 6.2.4 Microcontroller wiring, I have added a « piggy back » connector to the microcontroller board in order to be able to connect a DS18B20 temperature sensor to be used for measuring the brood temperature inside of the hive.

The DS18B20 sensor is a "one wire" sensor (using a single "data" wire in addition to the power supply), with the possibility of putting several sensors in parallel sharing the same "data" wire.

To do this, two libraries need to be added : "OneWire" and "DallasTemperature". The code is then as follows:

#include <OneWire.h>

#include <DallasTemperature.h>

// Data wire is plugged into pin GPIO 5
#define ONE_WIRE_BUS 5 // This line is part of parameters.h header file // Setup a oneWire instance to communicate with any OneWire devices OneWire oneWire(ONE_WIRE_BUS);

// Pass our oneWire reference to Dallas Temperature.
DallasTemperature sensors(&oneWire);

void setup(void)
{
sensors.begin();

Ardbeescale | Page 16 | Novembre 2021

}
void loop(void)
{
// call sensors.requestTemperatures() to issue a global temperature
// request to all devices on the bus
sensors.requestTemperatures();// Send the command to get temperature reading Serial.println("DONE");
Serial.print("Temperature is: "); Serial.println(sensors.getTempCByIndex(0)); // 0 means 1st device on the bus delay(1000);
}

### 2.1.6 Payloads formats

The sequence is very simple:

The program runs once every 15 minutes (this number can be changed remotely by sending an ad hoc downlink, see below) and puts the system in stand-by mode by cutting off the sensors' power supply as soon as it has finished doing what it has to do, i.e. :

1. Take a weight measure be reading the HX711
2. Take a temperature, humidity, pressure measure
3. Take a measure of the battery voltage
4. Take a temperature measure of the interior temperature of the hive
5. Pack all those measure in a « payload » to be transmitted to ttn network
6. Process the downlinks that may have been received

The program can indeed receive "downlinks" at the end of an uplink transmission.

These downlinks are sent either manually on the console or with | a python | program
(pushDownlink.py) running on the raspberry pi used for integration. It can also be sent by using
Blynk, which | is a smartphone IOT | application | communicating with | a python | program
(blynkMain.py) running on a rasperry pi.

These downlinks have different uses :

- Controlling the sirup pump feeding the hive with sugar sirup
- Changing the uplinks emission frequency
- Resetting the last downlink received by the node. Indeed, as LoRa communication is not 100% reliable (radio) it is necessary to check that the transmitted orders have been processed (for example the pump has actually supplied the hive with syrup). I have therefore included in the payload of each uplink the value of the last downlink received. When the verification is done, this value is reset to 0. This is the purpose of this command
- Sending a “hold measure” command, which is a time during which no measure will be taken in order to avoid polluting the monitoring graphs during the visits where the weight of the hive changes because the hive is open. We don’t want to take measure at that time.

Warning: to modify the length of the uplinks sent (=the size of the payload), it is necessary to modify two variables in the program: payloadBufferLength, which specifies the max size of the payloads, and payloadLength which defines the size of the uplink to be sent (of course it must be lower of equal to payloadBufferLength

The payload of the uplinks is organized on 9 bytes, as follows :

Byte 1 et 0 | Weight in multiples of 2g grams (the value is 10000 when the measured weight is 20000g). This is allowing to keep the weight on 2 bytes while maintaining a 2g resolution which is more than enough. The max weight is therefore 2 x 65536 = 131Kg, which is also more than enough
Byte 3 et 2 | temperature (coded on 2 bytes using function LMIC_f2sflt16 which codes a real between -1 and 1 to a 2 bytes integer

Ardbeescale | Page 17 | Novembre 2021
Byte 4 | humidity. Coded on 1 byte (resolution 1%)
Byte 5 | Atmospheric pressure on 1 byte: The number of mPa greater than 900 is transmitted
Byte 6 | Battery voltage on 1 byte : The value x25 is transmitted after removing the 0.
Byte 7 | value of the last downlink received by the node
Byte 8 | Hive internal temperature: coded on 1 byte: rounded value of actual 10 times (temperature minus 15). If measured temp is 34.6, 196 is transmitted.

The downlink payload is organized on 1 byte, as follows: :

Bits 7, 6 (command) | 0 0 Trigger of the pump | 0 1 Change of measure frequency / standby | 1 0 Reset « last downlink » sent with each uplink | 1 1 hold measure
Bits 5…Bit 0 (value) | Duration in multiples of 10 seconds (000010 means 40 seconds) Max is therefore 630 seconds) | 0 = once per mn 1 = every 2mn 2 = every 5mn 3 = every 10mn 4 = every 15mn 5 = every 30mn 6 = every heures 7 = every 2H 8 = every 6H 9 = every 12H 10 = every 24H 11 = no sleep (*) | | Time in multiples of 2mn (max is 126mn)

The "no sleep" mode (command 01-11, i.e. 4B) allows to easily reload a new firmware. Indeed, in normal mode, the processor is most of the time in standby mode, thus unable to manage the serial line that allows to reprogram the microcontroller. When we send the downlink 4B (75 in decimal), the processor never goes into standby and it becomes possible to reprogram it. To make it go back to normal mode (with sleep between two measurements), a downlink redefining the measurement frequency must be sent.
In fact I do not use this function (and I am not sure it works) because I included on the box a switch that allows to cut the power supply of the microcontroller. Knowing that the program starts with a waiting loop, it is possible to reprogram it by sending the new code while it is waiting in this loop (10 seconds). Warning: no 5V supply must be present on the micro USB connector because it goes directly to the microcontroller and cannot be cut by the on/off switch.
Warning : | If the pump goes on for a time longer than the interval between two measurements, this will delay the next measurement by the difference between these two times.

The table here below represents the list of possible downlinks :

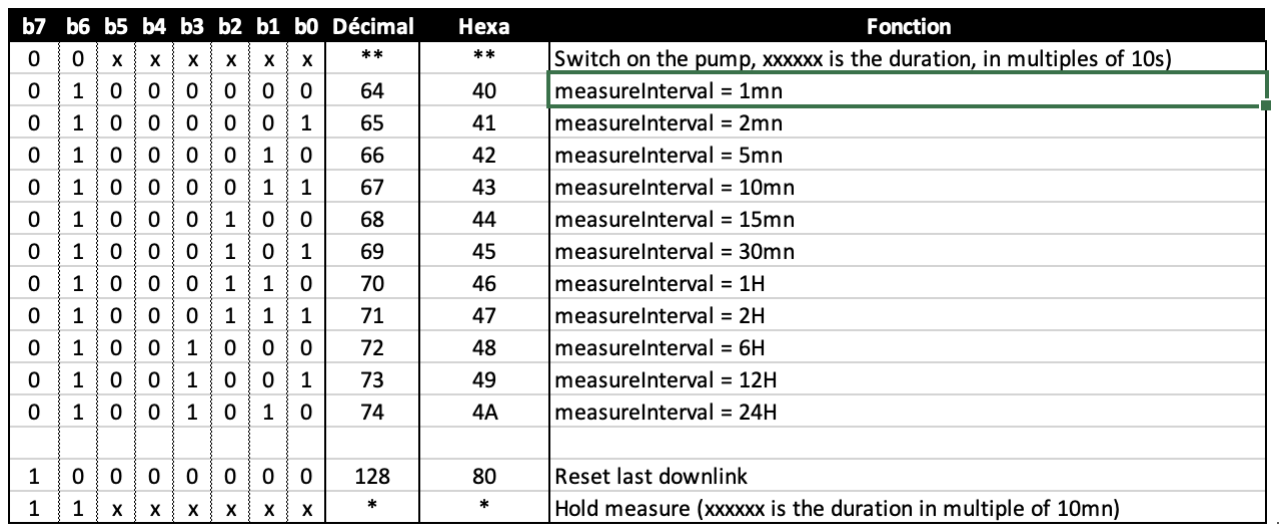
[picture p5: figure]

Ardbeescale | Page 18 | Novembre 2021

Additionally there is also one (and only one) type of downlink that is on three bytes instead of one byte: this is the command to update the system time. See explanation in 2.1.9

### 2.1.7 Main Sketch –uplinks and downlinks processing

LMIC-node (https://github.com/lnlp/LMIC-node) code is used as a template (see explanation in the readme on github) in which the user code must be added in three different parts:

- At the beginning if the sketch in order to define the global variables
- In the function process_work in order to read the sensor values
- In the function processDownLink in order to process downlinks
- At the end of the code, in the setup() function in order to initialize the sensors

The different places where user code can be added is clearly tagged with big signs « user code begins here » and « user code ends here » but I had to add code outside of these tags in order to manage the standy mode which is not part of LMIC-node. (See chapter 1.5 Energy)

Here is what my code does :

In its first part, it defines the constant that it needs (#define DHTPIN 10 ;
#define DHTTYPE DHT22; #define VBATPIN A7;…)

It loads the libraries that it needs and defines two global variables of type uint8_t:
- payloadBufferLength which needs to contain the length of the uplinks in number of bytes ; later in the code, it’s needed to also change variable payloadLength and give it this exact same value
- | lastDownlink | which | is | initialized | to | 0 | and | which | is | loaded | by the | function
processDownlink() with the value of the last downlink received by the node. All uplinks are sent with a byte (the last one) containing the value of this last downlink so that it’s possible to ensure that it has actually been received.

In the second part :

- Preparation of the uplink to be sent : the program reads the sensors (HX711, BME280, DS18B20) measure the battery voltage and put together the payload to be transmitted after coding the different elements
- Processing of the downlinks : the program checks if a downlink has been received and if yes determines which command has been received (bits 6 and 7) and acts accordingly:
- If those bits are 00, it means it’s a “trigger pump” command. The program then reads the value stored in bits 0 to 5, multiplies it by 30 and the result is the number of seconds during which the pump has to be turned ON.
- If those bits are 01, it’s a command to modify the measure frequency according to
downlink | table | in | chapter | 2.1.6. | The | program | will | then | change | variable
doWorkIntervalSeconds so that it is equal to the number of seconds between two measures, according to this table.

In the last part, which is in reality the beginning of the program, all the sensors are initialized (hx711, bme280 et DS18B20).

### 2.1.8 Main Sketch – power management

The MCCI_LMIC library works very well but leaves the processor running all the time, which is prohibitive for the battery. Stopping it by putting it in "sleep mode" is not easy because when you wake it up, the LMIC program will have lost its time reference. In fact it counts the ticks to decide when it will send a new uplink. So if we put it to sleep, it will start counting ticks from the moment we wake it up… We had to tinker in the LMIC code outside of the user code areas. See explanations chapter 1.5 Energy.

Ardbeescale | Page 19 | Novembre 2021

### 2.1.9 Main Sketch; time management

In "normal" operation, the time is not useful to the program because TTN network manages it: all the measurements received by the network are tagged with the time of reception. There is no need for the microcontroller to know the time and it is therefore initialized to 0 on power-up.

But this notion of time becomes necessary if you want to synchronize the sending of the measurement with the powering up of a gateway to avoid leaving the latter permanently powered up when powered from a battery recharged by a solar panel. A LoRa Gateway is quite power intensive and it’s difficult to maintain it always on when sun is not shining (see section 10 Power saving Unit)

So I included a mechanism that allows the actual time to be set-up in the microcontroller by sending a downlink of three bytes, containing respectively hours, minutes and seconds. This downlink must contain the precise time of the end of the next measurement.

The format of the time setting downlink is as follows :
- downlink[2] = seconds
- downlink[1] = minutes
- downlink[0] = hours

The program detects that this is a “time update” downlink because it is the only one that includes three bytes (all other downlinks are on a single byte).

In order to send uplinks at well determined times, when the gateway is powered on, the following logic is applied: each time a measurement frequency change downlink is received, the program is put in a waiting loop (before going to sleep mode), until the time of the microcontroller modulo the interval between two measurements is equal to 0. For example if we receive a downlink changing the measurement interval to 15mn, we wait for the time of the microcontroller to be XH00MN, XH15MN, XH30MN or XH45MN before going to sleep.

Because the gateway will be powered on only at certain times, it is necessary that the all microcontrollers are set-up with the same (preferably actual) time, which is not straight forward because the downlink containing the time is processed by the processor when it is sent but rather at the end of the transmission of the next uplink. And we do not know when the next uplink will be sent because when the unit is powered up, it is not synchronized with anything at all. Typically, if the time between two measurements is 15mn, the “reset time” downlink will be processed with a delay of 0 to 15mn, depending on when this downlink is sent.

In order to solve this problem two programs have been developed:

- getTime.py which takes as parameters the deviceId of the unit which time needs to be set, the number of minutes between two consecutive measurements on this unit.
Example : python getTime.py hso-energysaver 15
- setTime.py which takes as parameter the deviceId of the node
(python setTime.py hso-energysaver)

The program getTime.py will listen to the uplinks sent by the unit which deviceId is given as a parameter and will extract from this uplink its reception time. At this moment we know how long later the next uplink will be processed and therefore at what time (just after) a downlink sent before this next uplink will be processed. The program will therefore add to the reception time of the last uplink the number of minutes between two consecutive measurements (passed as a parameter to the program, together with the deviceId) and place this information in a file time.dat in directory /home/pi/Documents/deviceId

The program setTime.py, which must be launched before the previous one, listens to this directory and as soon as it detects a file in it, reads its content which is the time at which a downlink sent before the reception of the next uplink will be processed. It waits a few seconds then sends the “reset time” downlink command according to the format explained above (downlink of three bytes:
- downlink[2] = seconds
- downlink[1] = minutes
- downlink[0] = hours

Ardbeescale | Page 20 | Novembre 2021

Syntax: python setTime.py hso-energysaver

### 2.1.10 Dealing with unexpected hangs thanks to the integrated watch dog

From time to time but very rarely, one driver (I believe this is the BME280) fails to read correctly the sensor data and gets stuck. As a result, the node doesn’t communicate anymore, the sleep mode is not activated anymore and the battery gets empty rapidly.
After checking various resources I realized that such things can happen and in order to deal with that, the microcontroller includes a watchdog which can reset the system in case it is not refreshed regularly.

I use the watchdog timer from javos65 available on GitHub here. (https://github.com/javos65/WDTZero) The examples on GitHub speak for themselves with one exception: the watchdog must be cleared at least once every 32s, which obviously is shorter that the sleep time. I had therefore to disable the watchdog before putting the processor to sleep mode, which is not documented in the provided examples. Looking into the library it’s easy to determine that the watchdog can be disabled by calling it with 0 as the main variable: MyWatchDoggy.setup(0);

In my code, the watchdog object MyWatchDoggy is created in the setup section, then it is enabled just before the sensor reading section (MyWatchDoggy.setup(WDT_SOFTCYCLE32S);) and disabled at the end of this section with MyWatchDoggy.setup(0);

### 2.2 JS code for payload decoding (to be loaded on ttn console)

We start from Adafruit example here (https://learn.adafruit.com/the-things-network-for-feather/payload-decoding) which transmits and decodes only two values (temperature and humidity ) using 4 bytes. In our case, there are 6 values to be decoded, plus the value of last downlink, which is a total of 9 bytes. It will be done as follows (names that are underlined are the Javascript keys).

- weight : Byte 0 et 1 : weight in multiples of 2g (the value is 10000 for a measured weight of 2000g). Max weight is therefore 2 x 65536 = 131Kg, which is OK.
- temperature : Byte 2 et 3 (coding on 2 bytes using function LMIC_f2sflt16 which codes a real number between -1 and +1 into a 2 bytes integer.
- humidity : Byte 4 : Coding on 1 byte (resolution 1%, which is OK)
- pressure : Byte 5 : atmospheric pressure on 1 byte: the number de mPa greater than 900
- voltage : Byte 6 : battery voltage on 1 byte : this is the value of the voltage multiplied by 25 with no decimal because the value is on 1 bytes only.
- lastDownlink : this is the value of the last downlink received by the node (allowing to check that is has actually been received)
- internalTemp: hive internal temperature minus 20 and multiplied by 10

Corresponding Javascript code is therefore:

function Decoder(bytes, port) {
var decoded = {};
codedWeight = bytes[0] + bytes[1] * 256; decoded.weight = codedWeight *2;
codedTemp = bytes[2] + bytes[3] * 256; decoded.temperature = sflt162f(codedTemp) * 100 decoded.humidity = bytes[4];
decoded.pressure = bytes[5] + 900; decoded.voltage = bytes[6] /25; decoded.lastDownlink = bytes[7]; decoded.internalTemp = bytes[8]/10 + 15; return decoded;
}

function sflt162f(rawSflt16)
{
rawSflt16 &= 0xFFFF;
// special case minus zero: if (rawSflt16 == 0x8000)
return -0.0;
// extract the sign.

Ardbeescale | Page 21 | Novembre 2021

var sSign = ((rawSflt16 & 0x8000) != 0) ? -1 : 1; // extract the exponent
var exp1 = (rawSflt16 >> 11) & 0xF;
// extract the "mantissa" (the fractional part)
var mant1 = (rawSflt16 & 0x7FF) / 2048.0;
var f_unscaled = sSign * mant1 * Math.pow(2, exp1 - 15); return f_unscaled;
}

This code can be found is file ttn-decode.js

### 3 INTEGRATION WITH GOOGLE SHEET

This mode of integration is not optimal and I have never managed to have super reliability. Access to Google sheet crashes from time to time (once every 10 or 15 days) and I am not really sure why.
I | haven't | spent | a lot of time trying to catch | errors in | software | because | the | Node-
Red/InfluxDB/Grafana integration is preferable in many ways. It is nevertheless very practical to be able to retrieve the data in a Google Sheet file for the calibration of the sensors, in particular to determine the parameters necessary for the temperature compensation of the weight measurement.

### 3.1 MQTT

### 3.1.1 Protocol

The integration of TTN with the back-end is done using the MQTT protocol, available on the TTN console. MQTT will make it possible to get all the data received by the TTN server (the uplinks) and also to transmit to this server the data to be sent to the scales (the downlinks)

For explanation on MQTT and Mosquitto : see this video. (https://www.youtube.com/watch?v=FsSlgAWtGio&t=378s) Summary :
MQQT is a very lightweight and widely used M2M communication protocol over TCPIP. The sensors correspond to “topics”. They communicate with an MQTT server called an “MQTT broker”. To receive data from sensors that send data to the MQTT broker, a "subscribe" request is made. To send data to an actuator connected to the MQTT broker, a "publish" request is made. There seems to be 3 connection modes, presenting different connection reliabilities (0, by default, the link is sent once without backup, 1 and 2 are more secure) but the LoRaWAN network only manages the first mode (QoS= 0). This is why I have developed a mechanism to verify that the downlink has been received (the payload of each uplink includes the last downlink received).

The most common broker is "mosquitto" which runs on almost all platforms. It uses the MQTT protocol and therefore makes it possible to send “publish” and to subscribe to “topics”.

### 3.1.2 Mosquitto

The explanations below are for information only because I use a python library to communicate with the MQTT server of TTN.
I nevertheless tested access to the MQTT broker of TTN with the mosquitto commands and summarizes the manipulations made below.

Below is a procedure to load mosquitto on a Raspberry pi but it seems that there is a simpler and safer method consisting of using a so-called “docker” application (see explanations in chapter 5)

To load mosquito on raspberry :
sudo apt-get update
sudo apt-get upgrade
sudo apt-get install mosquitto mosquitto-clients

Need to edit the file mosquitto.conf in order to check « include_dir »: sudo nano /etc/mosquitto/mosquitto.conf
It includes the line include_dir /etc/mosquitto/conf.d
We now need to create a file default.conf containing this directory: sudo nano /etc/mosquitto/conf.d/default.conf

Ardbeescale | Page 22 | Novembre 2021

in which we put following lines :
allow anonymous false (in order to refuse anonymous connections)
password_file /etc/mosquito/pwfile
listener 1883 (1883 is the defaults port, which means this line is not really needed…) We need to create a user with following line:
sudo mosquitto_passwd -c /etc/mosquitto/pwfile userName
The program asks for the user code of userName and store it
Mosquito now needs to be restarted : sudo /etc/init.d/mosquitto restart

### 3.1.2.1 Subscription

A page of (https://www.thethingsindustries.com/docs/integrations/mqtt) TTN web site explains the different « topics » to which it’s possible to subscribe using the command mosquitto_sub. The syntax is as follows :

mosquitto_sub -h hostName -t "topic" -u "userName" -P "password" -d
(option -d means “enable debug messages », userName is the application_id of TTN where @ttn is added at the end)
- Hostname is eu1.cloud.thethings.network
- password is the API key provided by TTN (on the integration page)
- user name is {applicationId}@{tenantId} knowing that tenantId is the host name (ttn). See « MQTT integration (https://www.thethingsindustries.com/docs/integrations/mqtt/mqtt-clients/) » page
- The different « topic » are listed here below and it’s possible to subscribe to all topics by replacing "device_id" by "#"
- v3/{application id}@{tenant id}/devices/{device id}/join
- v3/{application id}@{tenant id}/devices/{device id}/up
- v3/{application id}@{tenant id}/devices/{device id}/down/queued
- v3/{application id}@{tenant id}/devices/{device id}/down/sent
- v3/{application id}@{tenant id}/devices/{device id}/down/ack
- v3/{application id}@{tenant id}/devices/{device id}/down/nack
- v3/{application id}@{tenant id}/devices/{device id}/down/failed
- v3/{application id}@{tenant id}/devices/{device id}/service/data
- v3/{application id}@{tenant id}/devices/{device id}/location/solved

In my case here is the command:

mosquitto_sub -h eu1.cloud.thethings.network -t "#" -u "ardbeescale-af01@ttn" -P "NNSXS.E5LAS7FKQAFUHNPXIDRKQOBAAFSCLGQPZIJE5SI.3C4MRNGCMAMZ6UE6VFJ3A653VPH2FICMF6UNNCYYKIHN5YVGVMFA" -d
(warning : the double quotes are not the same under word and under textEdit… The quotes to be used are those available in Terminal application)

### 3.1.2.2 Publications

Syntax is as follows :
mosquitto_pub -h thethings.example.com \
-t "v3/app1@tenant1/devices/dev1/down/push" \
-u "app1@tenant1" -P "NNSXS.VEEBURF3KR77ZR.." \
-m '{"downlinks":[{"f_port": 15,"frm_payload":"vu8=","priority": "NORMAL"}]}' \
-d`

In my case, in order to send 0C (which is wA== base 64) :
mosquitto_pub -h eu1.cloud.thethings.network -t "v3/ardbeescale-af01@ttn/devices/hive01-test2af/down/push" -u "ardbeescale-af01@ttn" -P "NNSXS.E5LAS7FKQAFUHNPXIDRKQOBAAFSCLGQPZIJE5SI.3C4MRNGCMAMZ6UE6VFJ3A653VPH2FICMF6UNNCYYKIHN5YVGVMFA" -m '{"downlinks":[{"f_port": 15,"frm_payload":"wA==","priority": "NORMAL"}]}' -d

It’s possible to replace /push by /replace in order to clear the downlinks present in the queue.

Ardbeescale | Page 23 | Novembre 2021

It’s also possible to ask for an AKN. See TTN doc here. (https://www.thethingsindustries.com/docs/integrations/mqtt/)

### 3.1.3 MQTT & python

### 3.1.3.1 Principle

See explanation about how to use this library here (http://www.steves-internet-guide.com/into-mqtt-python-client/) and there is also an explanatory video here. (https://www.youtube.com/watch?v=QAaXNt0oqSI)

The python library used to retrieve data from an MQTT broker and publish data is called paho. Documentation is available here. (https://pypi.org/project/paho-mqtt/#callbacks)

It needs to be installed on raspberry pi:
pip3 install paho.mqtt

The main class of this library is Client. It includes several methods :
- connect() and disconnect()
- subscribe() and unsubscribe()
- publish()
- username_pw_set()

The different steps are as follows:

Import in a python program: import paho.mqtt.client as mqtt

Instantiation of the client : client =mqtt.Client(client_name)
client_name is optional. If left blank the system will affect a name

Connection to broker : connect(host, port=1883, keepalive=60, bind_address="")
with TTN, host is : eu1.cloud.thethings.network

In all the examples that I found, the connection to the broker is done by the command above, without specifying the user_name or the password. But by reading the docs of the library, we see that there is a command (method) to specify these parameters with the connection: username_pw_set(username, password)

Therefore, in order to publish a message, the sequence is as follows :

USER = "ardbeescale-af01@ttn"

PASSWORD = "NNSXS.E5LAS7FKQAFUHNPXIDRKQOBAAFSCLGQPZIJE5SI.3C4MRNGCMAMZ6UE6VFJ3A653VPH2FICMF6UNNCYYKIHN5YVGVMFA"
DEVICE_ID = "hive01-test2af"
PUBLIC_ADDRESS = "eu1.cloud.thethings.network"
PUBLIC_ADDRESS_PORT = 1883
mqttClient = mqtt.Client()
mqttClient.username_pw_set(USER, PASSWORD) mqttClient.connect(PUBLIC_ADDRESS, PUBLIC_ADDRESS_PORT, 60) topic = "v3/" + USER + "/devices/" + DEVICE_ID + "/down/push" hexadecimal_payload = '0C'
fport = 100
# Convert hexadecimal payload to base64

b64 = b64encode(bytes.fromhex(hexadecimal_payload)).decode()
msg | = | '{"downlinks":[{"f_port":' | + | str(fport) | + | ',"frm_payload":"' | + | b64 | +
'","priority": "NORMAL"}]}'
result = mqttClient.publish(topic, msg, QOS)

It’s possible to replace /push by /replace in order to clear the other downlinks present in the queue. It’s possible to send several downlinks (a downlink is an array)
It’s also possible to ask for an AKN. See documentation here. (https://www.thethingsindustries.com/docs/integrations/mqtt/)

For “subscriptions” it’s needed to use the so called « callback functions ». Basically, each time a message is received (or a connection is established, or broken…), the script launches a function that will process this event. These are called “callback functions”. For each of those events, you have to

Ardbeescale | Page 24 | Novembre 2021

define what the corresponding callback function does and tell the instantiation object of the class (the MQTT client) what this function is. And for the callback functions to be activated, the program must listen; this is what we do with the method loop(timeout), timeout being the time during which this function blocks the program. It’s possible to use loop_forever() in which case the program will loop forever as the name suggests or to use loop_start() to launch an independent thread which do not block the program, which can be stopped with loop_stop()

Callback functions cannot return a value. There are several possibilities to retrieve the values of a received message:

- Declare a global variable using the global statement
- Use a list declared in the main function.
- Use a dictionary declared in the main function.
- Use an Object declared in the main function.

### 3.2 Python code running on Raspi serveur

In order to understand paho.mqqt, see explanation here. (http://www.steves-internet-guide.com/loop-python-mqtt-client/)

This is the code that retrieves the uplinks and the one that places them in a gsheet file.

### 3.2.1 Programs & data organization

Initially the programs were written to manage multiple scales (6) by loading data in the correct order into a google sheet file so that a dashboard is updated correctly. Today I use these programs only to calibrate scales (determination of temperature compensation parameters) and therefore some parts of the code may look weird because I kept the initial code structure which contains complexities that have become unnecessary .

Each hive sends its own uplinks. All the hives of the same apiary are on the same application in TTN so the paho mqtt library will receive the uplinks of all the hives of the same apiary (you can choose to subscribe to all the topics or to only one) .

The application_id that I have chosen is ardbeescale-af01 and the node names are respectively : hso-scale01 to hso-scale06 plus hso-energysaver.

Two pythons programs are used:

getdataFromUplink.py
Retrieves the uplinks from the MQTT server and store them in a file (the callback function which receives the messages will place the data received in the directory application_id of directory hiveDataRootDir (hiveDataRootDir being defined in the configuration file). New files created in this directory have the form YYYMMDDTHHMM#deviceId; they contain a python list : [weight, temperature, humidity, pressure, voltage]
(internal temperature measurement has been added later and is therefore not taken in account in this “google sheet” integration)
More details on this program in 3.2.3

storedata.py
Processes the file created by getDataFromUplink.py and store corresponding information in a google sheet file. Each time a file is created in the target directory, the program will catch it thanks to the pyinotify logic and will store corresponding data in the google sheet program. The way the data are stored in the gsheet file may seem weird; this is again because originally the file was used in a different purpose (example: the data are stored at the bottom of the file and rolled up by one row each time there is a new measure).
More details on this program in 3.2.4

Ardbeescale | Page 25 | Novembre 2021

Note:
I had to install gspread by doing a git clone (from the pythonScripts directory of my raspberry) (git clone https://github.com/burnash/gspread.git ) and for the set-up, the command is sudo python3 setup.py install to be launched from within directory gspread

It’s also needed to install module oauth2client :
sudo apt-get update
sudo apt-get install python3-oauth2client

### 3.2.2 Python configuration file

Its name is config_ardbeescale-af01.py and it contains following parameters:

- hiveDataRootDir : root directory in which getdatafromUplink.py will store the data received from the MQTT server.
- The list of nodes for this application :
hiveList=[device_id1, deviceId2, ,,deviceId6] The program checks if the uplink it get from the MQTT broker corresponds to a node that it needs to register in the gsheet file. The position of the deviceId in the list tells the program in which column of the google sheet file it needs to store the data.
- hiveSelectedForTHP : It is the number (1 to 6) of the scale which temperature, humidity and pressure are stored in the google sheet. The others, which also measure external T, H and P are not stored in the file.
- measureIntervalMn : it’s the time, in number of minutes, between two consecutive measures. The program needs to know that because it receives uplinks at different times and group the uplinks on a same line in the google sheet and it needs therefore to calculate round times.
- gSheetLastLineNbST : for some reasons that are not valid anymore now that I am not using any more the gsheet file to create a dashboard, new lines are added at the bottom of the gsheet file. Each time a new line has to be added, the first line (after the title line) is deleted and the new data are added line gSheetLastLineNbST
- gSheetLastLineNbLT : the sheet « LT » stores the first data of each day. Same principle : a new line is added at the bottom of the file.

### 3.2.3 Retrieving data from MQTT and temporary storage

Script getdataFromUplink.py

The script retrieves all the uplinks issued by the nodes listed in the configuration file config_ardbeescale-af01.py in a python list named “listOfScales” corresponding to the user (=application) mentioned in the program together with the credentials (which can be retrieved from TTN console in the “MQTT” integration page).

The program from mqtt paho library is launched by the line mqttc.loop(10) – with 10 meaning a timeout of 10s or by the line mqttc.loop_forever(). Each time an event occurs (a connection, a subscription, an incoming message…), a « callback function » is called (on_connect, on_subscribe, on_message…); each of those callback functions must be defined in the program:
mymqtt = mqtt.Client()
mymqtt.on_connect = on_connect
mymqtt.on_subscribe = on_subscribe
mymqtt.on_message = on_message
mymqtt.on_disconnect = on_disconnect

The callback functions are called by the occurrence of an event coming with several parameters. If the event is on_message, one of those parameters is message and it contains all the information pertaining to the uplinks just received (message.payload, message.topic, message.qos…).

Therefore this is in the callback function on_message that we will retrieve the information contained in the uplink; they can be found in the json object message.payload.

Ardbeescale | Page 26 | Novembre 2021

It is therefore needed to load the python module « json » which includes a method called loads allowing to get the uplink content in a python dictionary :

import json
# parse jsonObject:

jsonDict = json.loads(message.payload) # the result is a Python dictionary:

In order to understand what this dictionary is containing, the best is look at the structure of the json object sent by TTN (message.payload). This is available on TTN web site here. (https://www.thethingsindustries.com/docs/reference/data-formats/) In summary the most important keys of the dictionary are:

"end_device_ids" (which is also a dictionary, containing device_id, dev-EUI, etc…) "received_at" (date and time the message was received in format ISO 8601 UTC) "uplink_message" (dictionary containing all the uplink info)

This dictionary uplink_message contains a key frm_payload which is the raw (=not decoded) payload and a key decoded_payload allowing to access to a dictionary which keys are field names of the values transmitted (temperature, humidity…) as defined in the JavaScript file decoding the data on TTN, the values of those keys being those transmitted by the node.

Retrieving device_id :
If jsonDict is the dictionary coming from the json object message.payload, device_id can be retrieved as follows:
endDevice_idsDict = jsonDict["end_device_ids"]
device_id = endDevice_idsDict["device_id"]

Retrieving of uplink receiving time :
received_at = jsonDict["received_at"]
Warning : this is UTC time, shifted by 1H versus CET in winter and 2H in summer.

Retrieving of uplink data :
uplink_message = jsonDict["uplink_message"]
uplink_message is a dictionary containing decoded_upload :

decoded_payload = jsonDict["uplink_message"]

The data sent by the node can be found in the dictionary decoded_payload weight = decoded_payload["weight"]
temperature = decoded_payload["temperature"]
humidity = decoded_payload["humidity"]
pressure = decoded_payload["pressure"]
voltage = decoded_payload["voltage"]

These data are then loaded in a list [weight,temperature,humidity,pressure,voltage] which is stored in a file in a directory that is hard coded in the program line 63. File name includes device_id and time of receiving :
/home/pi/Documents/hiveData/ardbeescale-af01/2021-11-18T21:41#hso-cale01

### 3.2.4 Data storage in a google sheet file

Script storedata.py

Warning: as opposed to getdataFromUplink.py which stores the data in a directory that is hard coded, the directory in which storeData.py detects file creation is not hard coded but specified in the configuration file ardbeescale-af01.py this is because I do not use this integration for anything else than calibration I have not taken the time align the two programs. It is therefore important to check that the variable « hiveDataRootDir » in the configuration file is the same as the hard coded directory of getdataFromUplink.py line 63.

Ardbeescale | Page 27 | Novembre 2021

storeData.py also kept the mechanics of setting the name of the configuration file (initially there was one configuration file per apiary because the gsheet integration system was made to manage several apiaries). It is now useless but it is not changed.

Each time a file is created in /home/pi/Documents/hiveData/ardbeescale-af01/ pyinotify will detect it and will store it in the gsheet file (which name is simply the application name, ardbeescale-af01 in my case)

There are several possible implementations of pyinotify. I have used what I did in my old rasbeescale project with following code :

import pyinotify
wm = pyinotify.WatchManager() # Watch Manager
# events to watch:

mask = pyinotify.IN_DELETE | pyinotify.IN_CREATE | pyinotify.IN_CLOSE_WRITE
class EventHandler(pyinotify.ProcessEvent):
def process_IN_CLOSE_WRITE(self, event):
print(("File just closed:", event.pathname) def process_IN_CREATE(self, event):
print ("File created:", event.pathname) handler = EventHandler()
notifier = pyinotify.Notifier(wm, handler)
wdd = wm.add_watch("/home/pi/Documents/pythonScripts", mask, rec=True) notifier.loop()

The program retrieves the device_id and the time of uplink reception from the file content and the data of the uplink from the list stored in this file. The complete path of the file is returned by pyinotify and has following form: path=’/home/pi/Documents/hiveData/ardbeescale-af01/2021-11-18T17:03#hive01-test2af’

The formula to get device_id is : device_id=path[path.index("#")+1:]
(string[n:p] returns the characters n to p of string – if p is omitted, it returns all the characters from n up to the end of the string.

To get the date of reception of the uplink :
year = path[path.index(“T”)-10: path.index(“T”)-10+4] month = path[path.index(“T”)-5: path.index(“T”)-5+2] day = path[path.index(“T”)-2: path.index(“T”)-2+2] hour = path[path.index(“T”)+1: path.index(“T”)+1+2]
mn = path[path.index(“T”)+4: path.index(“T”)+4+2]

All the hives do not send their data at the same time, but we want to store in the gsheet file all the data received "about the same time" on the same line. With each uplink it is therefore necessary to determine whether to add a line or whether it is the transmission of a hive which is “almost” simultaneous with an uplink already received. For this, we will calculate the arrival time of the uplink in number of minutes since midnight, modulo the interval between two measurements (found in the measureIntervalMn variable, the same for all the hives). Thus, if the interval between two measurements is 5 minutes, two uplinks received respectively at 4:02 p.m. and 4:03 p.m. will be stored in the gsheet file at 4:00 p.m. When receiving each uplink, we calculate this modulo the interval between two measurements then we will read the reception time of the last uplink received on the last line of the gsheet file, also modulo measureIntervalMn. If these two values are the same, we will simply store the data of the uplink on the last existing line of the gsheet file whereas if the reception time of the uplink modulo the time interval between two measures is later than the value of the time read on the last line of the gsheet file (always modulo the same number), we will add a new line in this file

Retrieval of the time of the last uplink from the google sheet file (the result is a string):
(see chapter 8 below on how to install the python google sheet library)

lastLineDateTime = wks.cell(1,config.gSheetLastLineNb).value qui est de la forme '20/11/2021 21:42:51'

Ardbeescale | Page 28 | Novembre 2021

How to get the time of the last line:
lastLineTime = lastLineDateTime[lastLineDateTime.index(" ")+1:lastLineDateTime.index(" ")+6]

Then the number of minutes since midnight :
lastLineMn = int(lastLineTime[0:2])*60+int(lastLineTime[3:5])

And finally this same number, minus the value modulo the measurement interval: lastLineMnRounded = lastTimeMn - lastLineMn % config.measureIntervalMn

The same calculation is done on the reception time of the uplink, which was calculated before from the file containing the uplink:
lastUplinkMn = 60*int(hour)+int(mn)
lastUplinkMnRounded=lastUplinkMn – lastUplinkMn % config.measureIntervalMn

And to determine if we are on a new line or if it is the measurement supposed to be "roughly"
concomitant | with | those | already | received, | we | compare | lastLineMnRounded | and
lastUpLinkMnRounded.

If the two values are different, we will access the gsheet file to delete the top line and add a new line at the bottom (we proceed in this way so that the graphs on the dashboard continue to point to the right data as we fill in the data. When adding a line, we check whether there has been a date change since the last measurement and if so, we copy the line of data corresponding to the last measurement of the previous day in the “LT” sheet (for long term).

Then we simply load the data corresponding to the uplink being processed in the right cell of the gsheet file. Detecting the number of the hive to which the uplink being processed corresponds (by accessing the configuration file) makes it possible to put the data in the right cells (column). Moreover, if it is the hive that we want to use to record temperature, humidity and pressure (this hive number is specified with the parameter hiveSelectedForTHM of the configuration file) we also load this data on the line. The temperature, humidity and pressure data from the other sensors are ignored.

The date requires a special treatment because it is available in the script in the following variables: year, month, day, which represent the date of reception of the uplink and for the hours and minutes in the variable lastUplinkMnRounded which represents the number of minutes since midnight. We convert the latter into hour and mn and we convert these 5 variables into a string to have a DD/MM/YYY HH:MN type format that we put in a dateTimeString variable. With this character string, we will create a datetime type object:

dateTimeObj = datetime.datetime.strptime(dateTimeString, '%d/%m/%Y %H:%M')
It remains to convert this object into an excel date:
delta = dateTimeObj - datetime.datetime(1899,12,30)
XLdate = float(delta.days) + (float(delta.seconds)/86400)

Accessing google APIs to update gsheet file is simple (see explanation chapter 8) but I added a mechanism to manage cases where we exceeded the maximum number of API calls per unit of time defined by google (I think it's 100 every 100 seconds). This mechanism makes it possible to slow down the accesses to go below this limit. With a frequency of uplinks of 4 or 5 per hour, this mechanism is useless and can be removed.

### 3.2.5 Installation

The google sheet file name used to be a parameter (when I wanted to use this type of integration in real life) but now it is hard coded in two python script files getDataFromUplink.py and storedata.py

It is necessary that the gsheet file be filled with at least two lines of measures otherwise the program crashes because it tests if the day of the last measurement is the same as the day of the previous measurement (the change of day triggers the registration of the last measurement in the “sheet” named LT. There is no error catching.

Ardbeescale | Page 29 | Novembre 2021

There are a few libraries to load (remember to update and upgrade before…):

- pyinotify (sudo pip install pyinotify)
- paho.mqtt (sudo pip3 install paho.mqtt)

The programs to load are:
- getdataFromUplink.py This is the program that listens to the TTN broker, which decodes the data received and stores it in the corresponding apiary directory (/home/pi/Documents/hiveData/application_id). The file contains a python list and the file name is in the form of
filePath = "/home/pi/Documents/hiveData/"+application_id+"/"+received_at[0:16]+"#"+device_id
- storedata.py This is the program that takes care of storing the data received in the gsheet file
(specified | in | the | program), each | time | a | new | file | is | dropped | in | the | directory
/home/pi/Documents/hiveData/application_id by the script getdataFromUplink.py

My scripts are located in the directory /home/pi/Documents/pythonScripts .
The parameter hiveDataRootDir must be defined in config_application_id.sys (in my case hiveDataRootDir = "/home/pi/Documents/hiveData")

To generate the google sheet file, the best is to copy an existing one and renaming it. You must then follow the procedure explained in chapter 8 in order to install the right library which will access the gsheet (gspread).

The name of the credential file must be application_id_secret.json
(in my case ardbeescale-af01_secret.json)

Need also to create the directory containing the log files (which name is specified in parameter logFile in config file)

### 4 BLYNK

### 4.1 General Principle

To communicate with the scales, I use the Blynk IOT technology which allows, from a smartphone app, to send commands to (or read sensors from) IOT devices. In our case, Blynk will be used to communicate with only one device: the Raspberry pi which receives commands from the Blynk application from which it will determine which downlinks to send to which scale. Communication in the other direction will be used to retrieve the "lastDownlink" value from the uplinks sent by each scale together with the time at which it was received. This is done to verify that the last downlink sent has actually been received. The other data (weight, temperature, etc...) are visualized with Grafana thanks to the integration described in the next chapter: 5 node-RED – influxDB – Grafana. Blynk app is not used for that purpose (it could) except external temperature, humidity and atmospheric pressure which are also retrieved from the raspberry pi receiving the uplinks, and shown on the Blynk app screen.

In the future, it is possible to consider using Blynk to visualize the data of the different scales. To do this, you simply subscribe to the corresponding topics, decode them and send to Blynk the value of the different elements.

Blynk's billing method is based on the number of IOT devices controlled by the application. In our case there is only one, so the application is free.

### 4.2 Blynk set-up

Need to go to blynk.io and log in. A « Template » needs to be created. I understand that a template is a group of widget applicable to all devices of the same kind. The name of the template must be entered, as well as the hardware type and the type of connection.

The site gives then what is called « tokens » :

Ardbeescale | Page 30 | Novembre 2021

#define BLYNK_TEMPLATE_ID "TMPL1dONedlg"

#define BLYNK_DEVICE_NAME "ardbeescaleHSO"

Then we need to add a "datastream" (which are the old "Virtual Pin") corresponding to the data we want to manipulate. In the free version you can define a maximum of 30 widgets per template.

On the smartphone app (or in the web dashboard), you define the widgets (a button to trigger the pumps, a field to display data...) and you associate to each of these widgets a virtual pin. In the first Blynk docs, there was a notion of "read" and "write" to respectively transmit a data to the smartphone (display) or from the smartphone (command) but it seems that these notions of read and write have disappeared in version 2 because each time, the syntax of the code is "write".

The distribution of the virtual pins chosen is as follows:

| Déclenchement pompe (write) | Reset last downlink (write) | Last downlink (read) | Time of last uplink (read))
Pompe #1 | V1 | V7 | V13 | V18
Pompe #2 | V2 | V8 | V14 | V20
Pompe #3 | V3 | V9 | V15 | V21
Pompe #4 | V4 | V10 | V16 | V22
Pompe #5 | V5 | V11 | V17 | V23
Pompe #6 | V6 | V12 | V18 | V24
V0 | : 12V battery voltage
V25 : External temperature (mean temperature of all scales) V26 : External humidity (mean humidity of all scales)
V27 : External pressure (mean pressure of all scales)

V28 : choice of the number of hours during which the measurements are blocked (selecting 2 means
| you can manipulate the hive during two hours w/o polluting the weight chart because no measurement will be taken during 2 hours)

V29 : Triggering the blocking of measures. Once V28 has been set, the measures start to be blocked
| when the V29 button is pushed

Another Blynk screen could be develop to add some functionalities which currently can be accessed only from a python program running on the raspberry pi. Those functionalities are:

- Selection of measurement frequency
- Triggering of measurement frequency change
- Number of minutes that the gateway is powered-up before the time of sending the uplink
- Number of minutes during which the gateway is powered after the time of sending the uplink
- Permanent power supply to the gateway (C0)
- Intermittent power supply to the gateway (C1)
- Setting the time of a scale

### 4.3 Programming

To write a data on the smartphone, via the virtual pin V2 the code is the following:

Ardbeescale | Page 31 | Novembre 2021

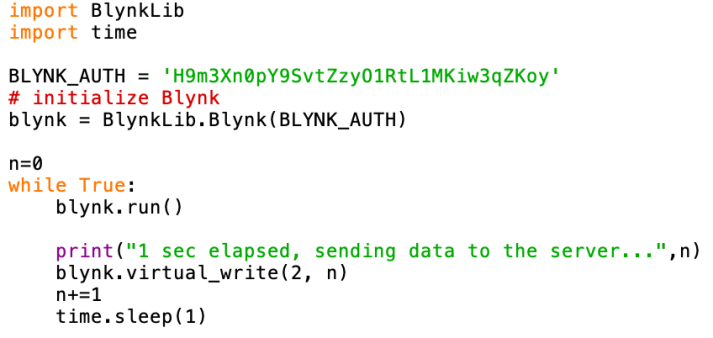
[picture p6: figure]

A number incrementing by one unit every second will be sent to the smartphone in a widget that is able to display this number

In the other way, the code to send a data from the app to the raspberry pi is as follow (the data is entered using an ad hoc widget connected to the right virtual pin, V0 in the example here below):

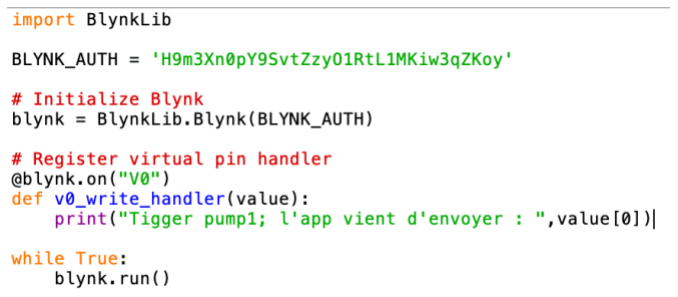
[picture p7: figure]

In order to read the contents of the uplinks emitted by the scales, we use the MQTT python library which, like Blynk, includes an infinite loop. It is therefore impossible to make a single program collecting the data from the uplink and displaying them on the smartphone.

Two programs are needed :

- getStoreUplinks.py uses the MQTT library to detect the arrival of uplinks (one per scale) then creates a file containing the data (payload) of this uplink and finally places it in a directory defined in the configuration file ardConf.py The file name in which the payload is stored is defined in the configuration file (lastUplink.dat is the default). This file contains a list which all the payload elements:
[uplinkTime,lastDownlink, weight, temperature,humidity,pressure,voltage,internalTemp]. It is stored in a directory which is /rootDirectory/application_id/device_id (rootDirectory is a parameter defined in ardConf.py – /media/pi/PI4HOME_HDD/uplinks/ in my case. Knowing that Blynk will regularly (once every 10s) read the stored data, it is important not to put this directory on the SD card of the pi. So I store the uplinks on an external disk. Be careful to change the access rights so that the program can access them:
sudo chown -R pi /media/pi/PI4HOME_MAIN
- blynkMain.py is in charge of writing this data on the smartphone. It will read the files in which the previous program is storing the uplinks payloads and display the corresponding information on the smartphone. In addition, this same program manages the buttons of the Blynk application of the smartphone allowing to trigger the pumps or to reset the value of the last received downlink.

For triggering the pumps, I have decided for simplicity that the volume of syrup is not adjustable in the app: the same quantity is always injected ; however it can be changed in the python configuration file ardConf.py (each scale can have a different volume).
Here is what the configuration file ardConf.py contains :
- All TTN access credentials

Ardbeescale | Page 32 | Novembre 2021
- The list of device_ids whose uplinks the program will listen to, in two distinct lists : listOfScales[] et otherDevices[]. Indeed, since these two categories of devices send uplinks of different formats, the program treats them differently.
- File name in which the uplinks will be stored
- Directory in which those files will be stored

The configuration file also contains a mapping used by the program sending downlinks (sendDownlink(DL) function, part blynkFunctions.py library). In order to send downlinks, the program blynkMain.py, uses this function sendDownlink(DL) where DL is a string parameter. The configuration file ardConf.py contains a dictionary which keys are these DL strings and which values are lists containing 2 elements: the first one is the downlink to be sent and the second one is the device numbers to which the downlink must be sent (this is the index+1 of the listOfScales[] list).

### 4.4 Blynk install on raspberry

Python libraries and corresponding documentation can be found on : https://github.com/vshymanskyy/blynk-library-python

### pip install can be used to install the library:

pip install blynk-library-python

But it seems that this command installs the old version of the library because I had an error message "invalid token" characteristic of a version miss-match. I had to go to the directory where the library was installed (/home/pi/.local/lib/python3.9/site-packages) and change the content of the BlynkLib.py file by the one present on github repository.

Alternatively, it’s possible to manually load the library :
From within the directory in which the library must be installed, type:

git clone https://github.com/vshymanskyy/blynk-library-python.git

The pythonpath must be updated with the directory in which this library has been installed :

sys.path.append('home/pi/Documents/pythonScripts/blynk-python-library')

### 4.5 Configuration of Blynk app

I am using only the free widgets available in Blynk (a lot of widgets used to be free in the previous Blynk version but only a few of them, the least fancy ones, are still free in the new version). A virtual pin has to be associated with each widget. My configuration is as follows:

V1 to V12 are virtual pins associated to “output” widgets (sending a command to the devices from the app). Those widgets are basic buttons: V1 to V6 are buttons triggering the sirup pumps et V7 to V12 are buttons resetting the value of “lastDownlink”.

V28 is also connected to an “output” widget which sends to the raspberry python program the time during which no measure should be taken (during hive manipulation). The time during which no measure are taken start when V29 button is pressed.

V0 and V13 to V27 are connected to “input” widget, which show on the screen values of parameters collected on the devices: V0 is the value of the 12V battery, V13 to V18 are showing the value of the last downlink received by each device, V19 to V24 are showing the time at which the last downlink has been received, V25 to V27 are respectively the temperature, humidity and atmospheric pressure measured in the apiary. Knowing that these value are measured by each scale, the values showed on the app are the average of all scales that are considered “valid”. This allows to eliminate one scale in case a sensor doesn’t work. Selecting the scales which temperature, humidity and pressure measurements are valid is done in the ardConf.py configuration file

Ardbeescale | Page 33 | Novembre 2021

Below are screen shots of the Blynk app. On the left the configuration screen and on the right the actual user screen:

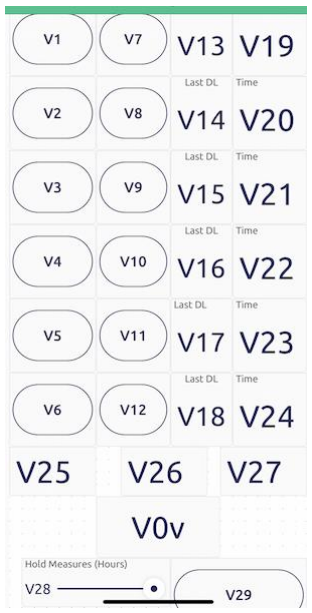
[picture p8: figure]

### 4.6 Update as of February 2023

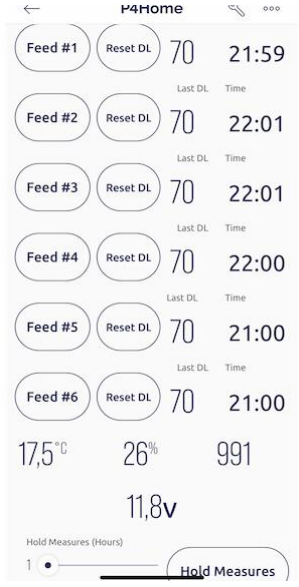
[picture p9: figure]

Blynk has released a note stating that as of February 28th 2023, the free version will accept only 10 virtual pin per template as opposed to 30 so far. I initially considered changing the set-up explained above in order to accommodate the new limitation by creating several templates instead of only one but it doesn’t seem to be possible and the only way seems to be an upgrade to the pay version (4.99€/month with yearly payment).

### 5 NODE-RED – INFLUXDB – GRAFANA INTEGRATION
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

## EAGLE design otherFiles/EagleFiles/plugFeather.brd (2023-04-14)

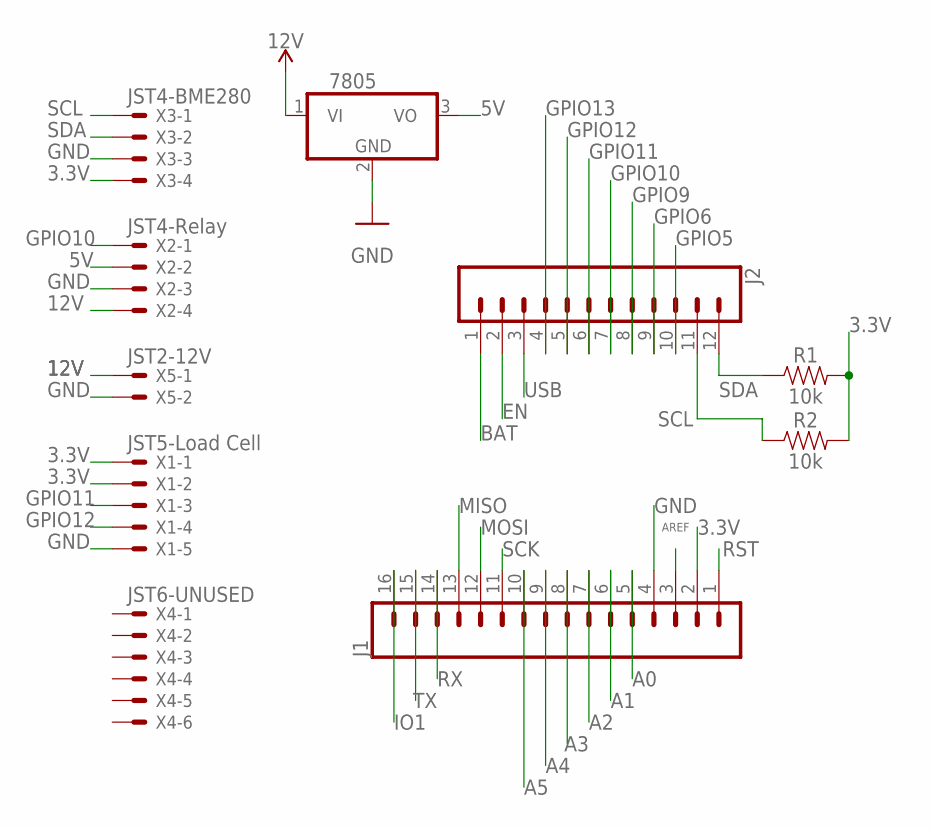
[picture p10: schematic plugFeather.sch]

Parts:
IC1: 7805; TO220V
J1: CONN_16; 1X16
J2: CONN_12; 1X12
R1, R2: 10k; AXIAL-0.3
X1: JST5-Load Cell; JST-XH-05-PACKAGE-LONG-PAD
X2: JST4-Relay; JST-XH-04-PACKAGE-LONG-PAD
X3: JST4-BME280; JST-XH-04-PACKAGE-LONG-PAD
X4: JST6-UNUSED; JST-XH-06-PACKAGE-LONG-PAD
X5: JST2-12V; JST-XH-02-PACKAGE-LONG-PAD

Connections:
3.3V: J1.2, R1.P$2 (2), R2.P$2 (2), X1.1, X1.2, X3.4
5V: IC1.3 (VO), X2.2
12V: IC1.1 (VI), X2.4, X5.1
A0: J1.5
A1: J1.6
A2: J1.7
A3: J1.8
A4: J1.9
A5: J1.10
AREF: J1.3
BAT: J2.1
EN: J2.2
GND: IC1.2 (GND), J1.4, X1.5, X2.3, X3.3, X5.2
GPIO5: J2.10
GPIO6: J2.9
GPIO9: J2.8
GPIO10: J2.7, X2.1
GPIO11: J2.6, X1.3
GPIO12: J2.5, X1.4
GPIO13: J2.4
IO1: J1.16
MISO: J1.13
MOSI: J1.12
RST: J1.1
RX: J1.14
SCK: J1.11
SCL: J2.11, R2.P$1 (1), X3.1
SDA: J2.12, R1.P$1 (1), X3.2
TX: J1.15
USB: J2.3

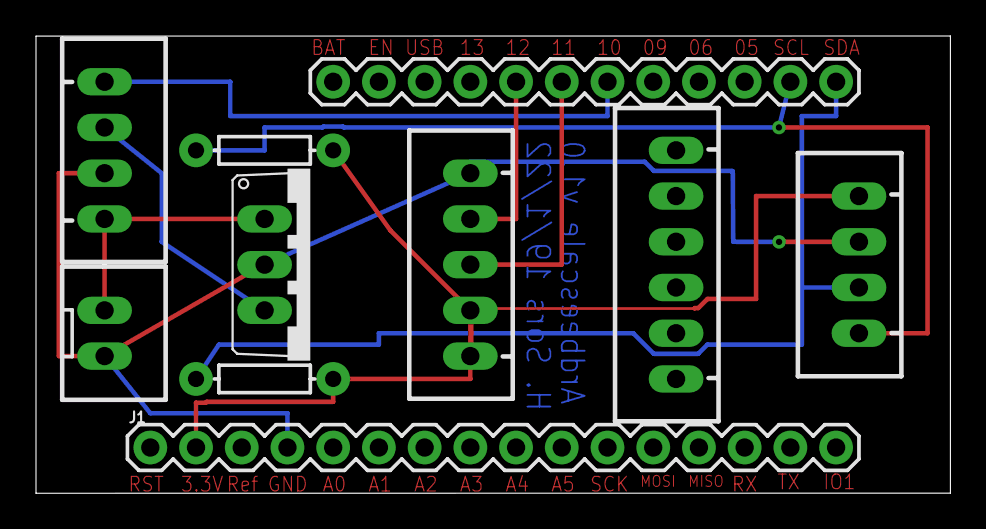
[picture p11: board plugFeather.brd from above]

Board: 2 copper layers, 50.8 x 25.4 mm, 10 parts (0 on the bottom side), 9 nets.

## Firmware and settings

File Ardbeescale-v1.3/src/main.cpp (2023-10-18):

/****************************************************************************
 *
 *  File:          LMIC-node.cpp
 * 
 *  Function:      LMIC-node main application file.
 * 
 *  Copyright:     Copyright (c) 2021 Leonel Lopes Parente
 *                 Copyright (c) 2018 Terry Moore, MCCI
 *                 Copyright (c) 2015 Thomas Telkamp and Matthijs Kooijman
 *
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
 *                 THE SOFTWARE IS PROVIDED "AS IS", WITHOUT ANY WARRANTY.
 * 
 *  License:       MIT License. See accompanying LICENSE file.
 * 
 *  Author:        Leonel Lopes Parente
 * 
 *  Description:   To get LMIC-node up and running no changes need to be made
 *                 to any source code. Only configuration is required
 *                 in platform-io.ini and lorawan-keys.h.
 * 
 *                 If you want to modify the code e.g. to add your own sensors,
 *                 that can be done in the two area's that start with
 *                 USER CODE BEGIN and end with USER CODE END. There's no need
 *                 to change code in other locations (unless you have a reason).
 *                 See README.md for documentation and how to use LMIC-node.
 * 
 *                 LMIC-node uses the concepts from the original ttn-otaa.ino 
 *                 and ttn-abp.ino examples provided with the LMIC libraries.
 *                 LMIC-node combines both OTAA and ABP support in a single example,
 *                 supports multiple LMIC libraries, contains several improvements
 *                 and enhancements like display support, support for downlinks,
 *                 separates LoRaWAN keys from source code into a separate keyfile,
 *                 provides formatted output to serial port and display
 *                 and supports many popular development boards out of the box.
 *                 To get a working node up and running only requires some configuration.
 *                 No programming or customization of source code required.
 * 
 *  Dependencies:  External libraries:
 *                 MCCI LoRaWAN LMIC library  https://github.com/mcci-catena/arduino-lmic
 *                 IBM LMIC framework         https://github.com/matthijskooijman/arduino-lmic  
 *                 U8g2                       https://github.com/olikraus/u8g2
 *                 EasyLed                    https://github.com/lnlp/EasyLed
 *
 ******************************************************************************/

#include "LMIC-node.h"


//  █ █ █▀▀ █▀▀ █▀▄   █▀▀ █▀█ █▀▄ █▀▀   █▀▄ █▀▀ █▀▀ ▀█▀ █▀█
//  █ █ ▀▀█ █▀▀ █▀▄   █   █ █ █ █ █▀▀   █▀▄ █▀▀ █ █  █  █ █
//  ▀▀▀ ▀▀▀ ▀▀▀ ▀ ▀   ▀▀▀ ▀▀▀ ▀▀  ▀▀▀   ▀▀  ▀▀▀ ▀▀▀ ▀▀▀ ▀ ▀

#include <Wire.h>
#include <Adafruit_Sensor.h>
#include "SparkFunBME280.h"
#include "DHT.h"
#include <RTCZero.h>
#include "HX711.h"
#include "hive-parameters.h"
#include <OneWire.h> 
#include <DallasTemperature.h>
#include "Arduino.h"
#include <WDTZero.h>

WDTZero MyWatchDoggy; // Define WDT (watchdog timer)

// init. BME280
BME280 myBME280;

/* Create an rtc object */
RTCZero rtc;

/* create an HX711 object */
HX711 scale;

/* Setup a oneWire instance to communicate with any OneWire devices   */
OneWire oneWire(ONE_WIRE_BUS); // ONE_WIRE_BUS is 5
// Pass our oneWire reference to Dallas Temperature. 
DallasTemperature sensors(&oneWire);

uint8_t lastDownlink = 0; // is sent with each uplink for akn purpose

const uint8_t payloadBufferLength = 9;    // Adjust to fit max payload length

/* Change these values to set the current initial time - will be done using a downlink */
byte seconds = 0;
byte minutes = 00;
byte hours = 00;
/* Change these values to set the current initial date */
const byte day = 01;
const byte month =01;
const byte year = 00;
/* stopMeasureTimeMn is the time during which no measure will be taken (as specified by the corresponding downlink when/if received) */
int stopMeasureTimeMn = 0;

/* Temperature compensation variables here below: code explanation can be found in document rasbeescale.docx, chapter "Temperature compensation" 
parameters used for temperature compensation are stored in file scale-parameters.h (/lib/ardbeescale directory) */

double deltaText[5];
double deltaTlc[5];
double Text[6] = {T_EXT_INIT,T_EXT_INIT,T_EXT_INIT,T_EXT_INIT,T_EXT_INIT,T_EXT_INIT};


//  █ █ █▀▀ █▀▀ █▀▄   █▀▀ █▀█ █▀▄ █▀▀   █▀▀ █▀█ █▀▄
//  █ █ ▀▀█ █▀▀ █▀▄   █   █ █ █ █ █▀▀   █▀▀ █ █ █ █
//  ▀▀▀ ▀▀▀ ▀▀▀ ▀ ▀   ▀▀▀ ▀▀▀ ▀▀  ▀▀▀   ▀▀▀ ▀ ▀ ▀▀ 


uint8_t payloadBuffer[payloadBufferLength];
static osjob_t doWorkJob;
uint32_t doWorkIntervalSeconds = DO_WORK_INTERVAL_SECONDS;  // Change DO_WORK_INTERVAL_SECONDS value in platformio.ini

// Note: LoRa module pin mappings are defined in the Board Support Files.

// Set LoRaWAN keys defined in lorawan-keys.h.
#ifdef OTAA_ACTIVATION
    static const u1_t PROGMEM DEVEUI[8]  = { OTAA_DEVEUI } ;
    static const u1_t PROGMEM APPEUI[8]  = { OTAA_APPEUI };
    static const u1_t PROGMEM APPKEY[16] = { OTAA_APPKEY };
    // Below callbacks are used by LMIC for reading above values.
    void os_getDevEui (u1_t* buf) { memcpy_P(buf, DEVEUI, 8); }
    void os_getArtEui (u1_t* buf) { memcpy_P(buf, APPEUI, 8); }
    void os_getDevKey (u1_t* buf) { memcpy_P(buf, APPKEY, 16); }    
#else
    // ABP activation
    static const u4_t DEVADDR = ABP_DEVADDR ;
    static const PROGMEM u1_t NWKSKEY[16] = { ABP_NWKSKEY };
    static const u1_t PROGMEM APPSKEY[16] = { ABP_APPSKEY };
    // Below callbacks are not used be they must be defined.
    void os_getDevEui (u1_t* buf) { }
    void os_getArtEui (u1_t* buf) { }
    void os_getDevKey (u1_t* buf) { }
#endif


int16_t getSnrTenfold()
{
    // Returns ten times the SNR (dB) value of the last received packet.
    // Ten times to prevent the use of float but keep 1 decimal digit accuracy.
    // Calculation per SX1276 datasheet rev.7 §6.4, SX1276 datasheet rev.4 §6.4.
    // LMIC.snr contains value of PacketSnr, which is 4 times the actual SNR value.
    return (LMIC.snr * 10) / 4;
}


int16_t getRssi(int8_t snr)
{
    // Returns correct RSSI (dBm) value of the last received packet.
    // Calculation per SX1276 datasheet rev.7 §5.5.5, SX1272 datasheet rev.4 §5.5.5.

    #define RSSI_OFFSET            64
    #define SX1276_FREQ_LF_MAX     525000000     // per datasheet 6.3
    #define SX1272_RSSI_ADJUST     -139
    #define SX1276_RSSI_ADJUST_LF  -164
    #define SX1276_RSSI_ADJUST_HF  -157

    int16_t rssi;

    #ifdef MCCI_LMIC

        rssi = LMIC.rssi - RSSI_OFFSET;

    #else
        int16_t rssiAdjust;
        #ifdef CFG_sx1276_radio
            if (LMIC.freq > SX1276_FREQ_LF_MAX)
            {
                rssiAdjust = SX1276_RSSI_ADJUST_HF;
            }
            else
            {
                rssiAdjust = SX1276_RSSI_ADJUST_LF;   
            }
        #else
            // CFG_sx1272_radio    
            rssiAdjust = SX1272_RSSI_ADJUST;
        #endif    
        
        // Revert modification (applied in lmic/radio.c) to get PacketRssi.
        int16_t packetRssi = LMIC.rssi + 125 - RSSI_OFFSET;
        if (snr < 0)
        {
            rssi = rssiAdjust + packetRssi + snr;
        }
        else
        {
            rssi = rssiAdjust + (16 * packetRssi) / 15;
        }
    #endif

    return rssi;
}


void printEvent(ostime_t timestamp, 
                const char * const message, 
                PrintTarget target = PrintTarget::All,
                bool clearDisplayStatusRow = true,
                bool eventLabel = false)
{
    #ifdef USE_DISPLAY 
        if (target == PrintTarget::All || target == PrintTarget::Display)
        {
            display.clearLine(TIME_ROW);
            display.setCursor(COL_0, TIME_ROW);
            display.print(F("Time:"));                 
            display.print(timestamp); 
            display.clearLine(EVENT_ROW);
            if (clearDisplayStatusRow)
            {
                display.clearLine(STATUS_ROW);    
            }
            display.setCursor(COL_0, EVENT_ROW);               
            display.print(message);
        }
    #endif  
    
    #ifdef USE_SERIAL
        // Create padded/indented output without using printf().
        // printf() is not default supported/enabled in each Arduino core. 
        // Not using printf() will save memory for memory constrainted devices.
        String timeString(timestamp);
        uint8_t len = timeString.length();
        uint8_t zerosCount = TIMESTAMP_WIDTH > len ? TIMESTAMP_WIDTH - len : 0;

        if (target == PrintTarget::All || target == PrintTarget::Serial)
        {
            printChars(serial, '0', zerosCount);
            serial.print(timeString);
            serial.print(":  ");
            if (eventLabel)
            {
                serial.print(F("Event: "));
            }
            serial.println(message);
        }
    #endif   
}           

void printEvent(ostime_t timestamp, 
                ev_t ev, 
                PrintTarget target = PrintTarget::All, 
                bool clearDisplayStatusRow = true)
{
    #if defined(USE_DISPLAY) || defined(USE_SERIAL)
        printEvent(timestamp, lmicEventNames[ev], target, clearDisplayStatusRow, true);
    #endif
}


void printFrameCounters(PrintTarget target = PrintTarget::All)
{
    #ifdef USE_DISPLAY
        if (target == PrintTarget::Display || target == PrintTarget::All)
        {
            display.clearLine(FRMCNTRS_ROW);
            display.setCursor(COL_0, FRMCNTRS_ROW);
            display.print(F("Up:"));
            display.print(LMIC.seqnoUp);
            display.print(F(" Dn:"));
            display.print(LMIC.seqnoDn);        
        }
    #endif

    #ifdef USE_SERIAL
        if (target == PrintTarget::Serial || target == PrintTarget::All)
        {
            printSpaces(serial, MESSAGE_INDENT);
            serial.print(F("Up: "));
            serial.print(LMIC.seqnoUp);
            serial.print(F(",  Down: "));
            serial.println(LMIC.seqnoDn);        
        }
    #endif        
}      


void printSessionKeys()
{    
    #if defined(USE_SERIAL) && defined(MCCI_LMIC)
        u4_t networkId = 0;
        devaddr_t deviceAddress = 0;
        u1_t networkSessionKey[16];
        u1_t applicationSessionKey[16];
        LMIC_getSessionKeys(&networkId, &deviceAddress, 
                            networkSessionKey, applicationSessionKey);

        printSpaces(serial, MESSAGE_INDENT);    
        serial.print(F("Network Id: "));
        serial.println(networkId, DEC);

        printSpaces(serial, MESSAGE_INDENT);    
        serial.print(F("Device Address: "));
        serial.println(deviceAddress, HEX);

        printSpaces(serial, MESSAGE_INDENT);    
        serial.print(F("Application Session Key: "));
        printHex(serial, applicationSessionKey, 16, true, '-');

        printSpaces(serial, MESSAGE_INDENT);    
        serial.print(F("Network Session Key:     "));
        printHex(serial, networkSessionKey, 16, true, '-');
    #endif
}


void printDownlinkInfo(void)
{
    #if defined(USE_SERIAL) || defined(USE_DISPLAY)

        uint8_t dataLength = LMIC.dataLen;
        // bool ackReceived = LMIC.txrxFlags & TXRX_ACK;

        int16_t snrTenfold = getSnrTenfold();
        int8_t snr = snrTenfold / 10;
        int8_t snrDecimalFraction = snrTenfold % 10;
        int16_t rssi = getRssi(snr);

        uint8_t fPort = 0;        
        if (LMIC.txrxFlags & TXRX_PORT)
        {
            fPort = LMIC.frame[LMIC.dataBeg -1];
        }        

        #ifdef USE_DISPLAY
            display.clearLine(EVENT_ROW);        
            display.setCursor(COL_0, EVENT_ROW);
            display.print(F("RX P:"));
            display.print(fPort);
            if (dataLength != 0)
            {
                display.print(" Len:");
                display.print(LMIC.dataLen);                       
            }
            display.clearLine(STATUS_ROW);        
            display.setCursor(COL_0, STATUS_ROW);
            display.print(F("RSSI"));
            display.print(rssi);
            display.print(F(" SNR"));
            display.print(snr);                
            display.print(".");                
            display.print(snrDecimalFraction);                      
        #endif

        #ifdef USE_SERIAL
            printSpaces(serial, MESSAGE_INDENT);    
            serial.println(F("Downlink received"));

            printSpaces(serial, MESSAGE_INDENT);
            serial.print(F("RSSI: "));
            serial.print(rssi);
            serial.print(F(" dBm,  SNR: "));
            serial.print(snr);                        
            serial.print(".");                        
            serial.print(snrDecimalFraction);                        
            serial.println(F(" dB"));

            printSpaces(serial, MESSAGE_INDENT);    
            serial.print(F("Port: "));
            serial.println(fPort);
   
            if (dataLength != 0)
            {
                printSpaces(serial, MESSAGE_INDENT);
                serial.print(F("Length: "));
                serial.println(LMIC.dataLen);                   
                printSpaces(serial, MESSAGE_INDENT);    
                serial.print(F("Data: "));
                printHex(serial, LMIC.frame+LMIC.dataBeg, LMIC.dataLen, true, ' ');
                serial.println();
            }
        #endif
    #endif
} 


void printHeader(void)
{
    #ifdef USE_DISPLAY
        display.clear();
        display.setCursor(COL_0, HEADER_ROW);
        display.print(F("LMIC-node"));
        #ifdef ABP_ACTIVATION
            display.drawString(ABPMODE_COL, HEADER_ROW, "ABP");
        #endif
        #ifdef CLASSIC_LMIC
            display.drawString(CLMICSYMBOL_COL, HEADER_ROW, "*");
        #endif
        display.drawString(COL_0, DEVICEID_ROW, deviceId);
        display.setCursor(COL_0, INTERVAL_ROW);
        display.print(F("sleep time:"));
        display.print(doWorkIntervalSeconds);
        display.print("s");
    #endif

    #ifdef USE_SERIAL
        serial.println(F("\n\nLMIC-node\n"));
        serial.print(F("Device-id:     "));
        serial.println(deviceId);            
        serial.print(F("LMIC library:  "));
        #ifdef MCCI_LMIC  
            serial.println(F("MCCI"));
        #else
            serial.println(F("Classic [Deprecated]")); 
        #endif
        serial.print(F("Activation:    "));
        #ifdef OTAA_ACTIVATION  
            serial.println(F("OTAA"));
        #else
            serial.println(F("ABP")); 
        #endif
        #if defined(LMIC_DEBUG_LEVEL) && LMIC_DEBUG_LEVEL > 0
            serial.print(F("LMIC debug:    "));  
            serial.println(LMIC_DEBUG_LEVEL);
        #endif
        serial.print(F("Sleep time:      "));
        serial.print(doWorkIntervalSeconds);
        serial.println(F(" seconds"));
        if (activationMode == ActivationMode::OTAA)
        {
            serial.println();
        }
    #endif
}     


#ifdef ABP_ACTIVATION
    void setAbpParameters(dr_t dataRate = DefaultABPDataRate, s1_t txPower = DefaultABPTxPower) 
    {
        // Set static session parameters. Instead of dynamically establishing a session
        // by joining the network, precomputed session parameters are be provided.
        #ifdef PROGMEM
            // On AVR, these values are stored in flash and only copied to RAM
            // once. Copy them to a temporary buffer here, LMIC_setSession will
            // copy them into a buffer of its own again.
            uint8_t appskey[sizeof(APPSKEY)];
            uint8_t nwkskey[sizeof(NWKSKEY)];
            memcpy_P(appskey, APPSKEY, sizeof(APPSKEY));
            memcpy_P(nwkskey, NWKSKEY, sizeof(NWKSKEY));
            LMIC_setSession (0x1, DEVADDR, nwkskey, appskey);
        #else
            // If not running an AVR with PROGMEM, just use the arrays directly
            LMIC_setSession (0x1, DEVADDR, NWKSKEY, APPSKEY);
        #endif

        #if defined(CFG_eu868)
            // Set up the channels used by the Things Network, which corresponds
            // to the defaults of most gateways. Without this, only three base
            // channels from the LoRaWAN specification are used, which certainly
            // works, so it is good for debugging, but can overload those
            // frequencies, so be sure to configure the full frequency range of
            // your network here (unless your network autoconfigures them).
            // Setting up channels should happen after LMIC_setSession, as that
            // configures the minimal channel set. The LMIC doesn't let you change
            // the three basic settings, but we show them here.
            LMIC_setupChannel(0, 868100000, DR_RANGE_MAP(DR_SF12, DR_SF7),  BAND_CENTI);      // g-band
            LMIC_setupChannel(1, 868300000, DR_RANGE_MAP(DR_SF12, DR_SF7B), BAND_CENTI);      // g-band
            LMIC_setupChannel(2, 868500000, DR_RANGE_MAP(DR_SF12, DR_SF7),  BAND_CENTI);      // g-band
            LMIC_setupChannel(3, 867100000, DR_RANGE_MAP(DR_SF12, DR_SF7),  BAND_CENTI);      // g-band
            LMIC_setupChannel(4, 867300000, DR_RANGE_MAP(DR_SF12, DR_SF7),  BAND_CENTI);      // g-band
            LMIC_setupChannel(5, 867500000, DR_RANGE_MAP(DR_SF12, DR_SF7),  BAND_CENTI);      // g-band
            LMIC_setupChannel(6, 867700000, DR_RANGE_MAP(DR_SF12, DR_SF7),  BAND_CENTI);      // g-band
            LMIC_setupChannel(7, 867900000, DR_RANGE_MAP(DR_SF12, DR_SF7),  BAND_CENTI);      // g-band
            LMIC_setupChannel(8, 868800000, DR_RANGE_MAP(DR_FSK,  DR_FSK),  BAND_MILLI);      // g2-band
            // TTN defines an additional channel at 869.525Mhz using SF9 for class B
            // devices' ping slots. LMIC does not have an easy way to define set this
            // frequency and support for class B is spotty and untested, so this
            // frequency is not configured here.
        #elif defined(CFG_us915) || defined(CFG_au915)
            // NA-US and AU channels 0-71 are configured automatically
            // but only one group of 8 should (a subband) should be active
            // TTN recommends the second sub band, 1 in a zero based count.
            // https://github.com/TheThingsNetwork/gateway-conf/blob/master/US-global_conf.json
            LMIC_selectSubBand(1);
        #elif defined(CFG_as923)
            // Set up the channels used in your country. Only two are defined by default,
            // and they cannot be changed.  Use BAND_CENTI to indicate 1% duty cycle.
            // LMIC_setupChannel(0, 923200000, DR_RANGE_MAP(DR_SF12, DR_SF7),  BAND_CENTI);
            // LMIC_setupChannel(1, 923400000, DR_RANGE_MAP(DR_SF12, DR_SF7),  BAND_CENTI);

            // ... extra definitions for channels 2..n here
        #elif defined(CFG_kr920)
            // Set up the channels used in your country. Three are defined by default,
            // and they cannot be changed. Duty cycle doesn't matter, but is conventionally
            // BAND_MILLI.
            // LMIC_setupChannel(0, 922100000, DR_RANGE_MAP(DR_SF12, DR_SF7),  BAND_MILLI);
            // LMIC_setupChannel(1, 922300000, DR_RANGE_MAP(DR_SF12, DR_SF7),  BAND_MILLI);
            // LMIC_setupChannel(2, 922500000, DR_RANGE_MAP(DR_SF12, DR_SF7),  BAND_MILLI);

            // ... extra definitions for channels 3..n here.
        #elif defined(CFG_in866)
            // Set up the channels used in your country. Three are defined by default,
            // and they cannot be changed. Duty cycle doesn't matter, but is conventionally
            // BAND_MILLI.
            // LMIC_setupChannel(0, 865062500, DR_RANGE_MAP(DR_SF12, DR_SF7),  BAND_MILLI);
            // LMIC_setupChannel(1, 865402500, DR_RANGE_MAP(DR_SF12, DR_SF7),  BAND_MILLI);
            // LMIC_setupChannel(2, 865985000, DR_RANGE_MAP(DR_SF12, DR_SF7),  BAND_MILLI);

            // ... extra definitions for channels 3..n here.
        #endif

        // Disable link check validation
        LMIC_setLinkCheckMode(0);

        // TTN uses SF9 for its RX2 window.
        LMIC.dn2Dr = DR_SF9;

        // Set data rate and transmit power (note: txpow is possibly ignored by the library)
        LMIC_setDrTxpow(dataRate, txPower);    
    }
#endif //ABP_ACTIVATION
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
void loop() 
{
    os_runloop_once();
}

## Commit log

2023-04-14 Connecte bee hive
    Complete step by step instructions to build a complete connected bee hive including temperature compensated weight, internal and external temp, humidity, pressure. Can also trigger sirup pump.
    [plugFeather.brd, plugFeather.sch]
2023-08-17 add watchdog timer
2023-08-20 Bug correction in the watch dog software
    Bug correction in the watch dog software
    [main.cpp]
2023-10-18 Bug fix
    - Addition of a watchdog routine catching the few cases where the SW hangs because of the BME280 driver failing to correctly read the sensor
    - New version of the instruction file
    [main.cpp]

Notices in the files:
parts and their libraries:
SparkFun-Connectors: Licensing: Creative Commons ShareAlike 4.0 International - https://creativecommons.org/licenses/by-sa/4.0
